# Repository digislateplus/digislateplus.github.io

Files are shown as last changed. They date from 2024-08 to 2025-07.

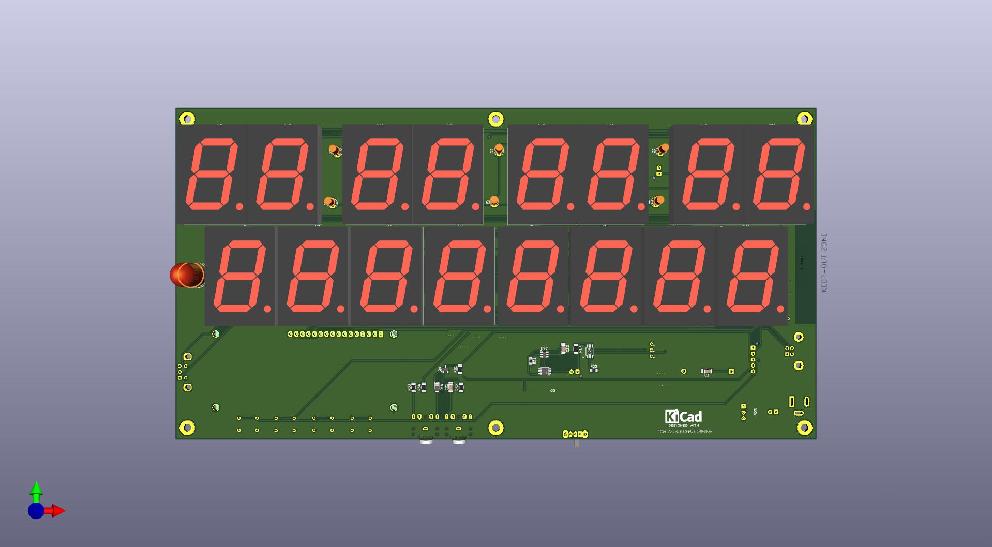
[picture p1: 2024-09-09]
hardware/PCB/gallery/DigiSlatePlus front.jpg

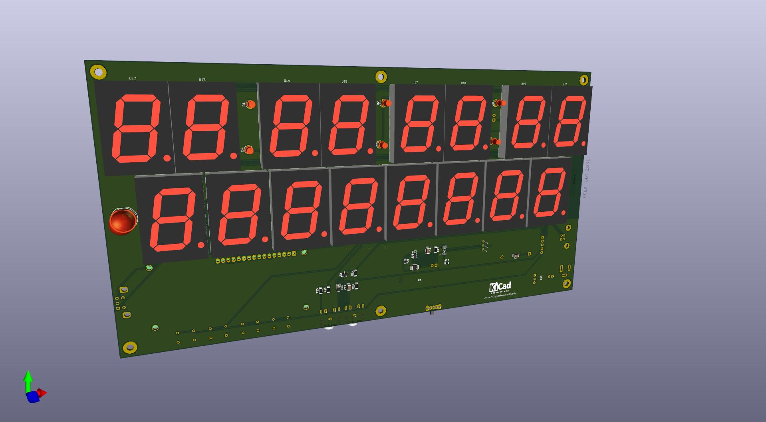
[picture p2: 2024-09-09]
hardware/PCB/gallery/DigiSlatePlus.jpg

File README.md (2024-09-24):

# DigiSlate+

DigiSlate+ is based on the [DigiSlate](https://www.youtube.com/watch?v=TnaWQZtmPek) and is inspired by the DIY timecode generator from [mitkunz](https://github.com/mitkunz/diy_timecode_generator). The aim for the DigiSlate+ is not only to be able to read and display timecode, but also to generate it itself. To make this possible, the hardware is extended by a real time clock with high running accuracy. The RTC module DS3231 with temperature-compensated quartz offers the possibility.

There are two versions of the DigiSlate+. The simpler version is based on modified hardware from the original DigiSlate project and the software in the master branch.

The newly developed hardware offers significantly more functions. The corresponding code can be found in the dotmatrix branch.

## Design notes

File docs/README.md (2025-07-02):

# DigiSlate+

- [Hardware](hardware.md)
- [Functions](function.md)
- [ToDos](todos.md)
- [Code](https://github.com/digislateplus/digislateplus.github.io)

DigiSlate+ is based on the [DigiSlate](https://www.youtube.com/watch?v=TnaWQZtmPek) and is inspired by the DIY timecode generator from [mitkunz](https://github.com/mitkunz/diy_timecode_generator). The aim for the DigiSlate+ is not only to be able to read and display timecode, but also to generate it itself. To make this possible, the hardware is extended by a real time clock with high running accuracy. The RTC module DS3231 with temperature-compensated quartz offers a maximum drift of two minutes per year or 8 frames in a day.

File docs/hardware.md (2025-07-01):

# Hardware

[Home](README.md)

The hardware is based on an ESP32S3 microcontroller, which supplies the time code, controls the displays and can connect to other devices via WiFi and Bluetooth.

All components are combined on a central circuit board, only the switch for recognising the flap, the main switch and the battery are connected via JST-XH connectors.

The 7-segment LED displays for the time code, scenes and take numbers are located on the front. The rear has the LC display, four buttons and a rotary encoder for controlling the functions.

The real-time clock has its own battery, which enables a long running time when the DigiSlate+ is switched off.

A 3.5mm jack is used for the input and output of the timecode. The DigiSlate+ can be powered via a 5.5x2.5mm DC plug. The DigiSlate can be supplied with a voltage between 8 volts and 24 volts via a 5.5 x 2.5 mm DC plug and the internal battery can be charged.

* [download]({{ site.baseurl }}{% link DigitSlate+ Schematics.pdf %})
* [download]({{ site.baseurl }}{% link DigitSlatePlus__Assembly.pdf %})

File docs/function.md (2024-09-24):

# Operation
## Start
The DigiSlate+ is put into operation using the switch on the bottom. After a short initialization, the time is read from the real-time clock. The time code is synchronized with the exact time base of the real-time clock and "init" is shown on the LC display.

Once initialization is complete, the time code starts running on the LED display. The LC display on the back shows "run" as well as the set frame rate and the user bits.

If the DigiSlate+ is operated, the sync LEDs flash and the time code display remains for three seconds. "clap" is shown on the LC display. After that, the time code continues to run again.

## Time code output
The time code is output at the tip of the 3.5 mm jack socket as an LTC with a voltage of 1 volt peak-to-peak.

## Time code input
An external time code can be fed in via the ring of the 3.5 mm jack socket.  The DigiSlate+ recognizes this and switches to reading mode. The read time code is shown on the LED display and the LC display shows "sync".

The time in the real-time clock is not changed. When the time code entry is finished, the DigiSlate+ goes back to "run" mode and shows the time of the real-time clock.

### Jam
The external time code can be transferred to the real-time clock.

1. Switch off the DigiSlate+

2. Feed the external time code via the 3.5mm jack socket
3. Switch on the DigiSlate+

It is in "jam" mode, which is shown on the LC display. The time code is transferred to the real-time clock as soon as it is folded once.

## Setup
Parameters of the DigiSlate+ can be set in the setup.

- Set time code
- Set user bits
- Select frame rate

### Start
The setup mode is started as follows.

1. Turn off the DigiSlate+
2. Turn on the DigiSlate+
3. When the text "tripple clap to enter setup" appears, quickly clap the DigiSlate+ three times.

"SETUP" will now appear on the LCD display.

(more to come)

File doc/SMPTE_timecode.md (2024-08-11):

# SMPTE/EBU timecode structure
[WikiAudio](https://www.wikiaudio.org/smpte-time-code/)

| Byte | Bit | content|
|---|-----|---|
| 0 | 0-3 |	frame units |
| 0 | 4-7 | user bits 1 |
| 1 | 8-9 | frame tens |
| 1 | 10  | dropframe bit*(1)* |
| 1 | 11  |	colorframe bit*(2)* |
| 1 | 12-15 | user bits 2 |
| 2 | 16-19 | seconds units |
| 2 | 20-23 | user bits 3 |
| 3 | 24-26 | seconds tens |
| 3 | 27 | bi phase mark correction bit |
| 3 | 28-31 | user bits 4 |
| 4 | 32-35 | minutes units |
| 4 | 36-39 | user bits 5 |
| 5 | 40-42 | minutes tens |
| 5 | 43 | binary group flag bit*(3)* |
| 5 | 44-47 | user bits 6 |
| 6 | 48-51 | hours units |
| 6 | 52-55 | user bits 7 |
| 7 | 56-57 | hour tens |
| 7 | 58 | unused, reserved(*4*) |
| 7 | 59 | binary group flag bit*(5)* |
| 7 | 60-63 | user bits 8 |
| 8-9 | 64-79 | sync word*(6)* |

(1) 1=drop frame (frame 0 and 1 omitted from first second of each minute, but included when minutes divides by ten; approximates 29.97 frame/s)

(2) i.e. the time code is intentionally synchronised with a color TV field sequence.

(3) (with bit 59, 43,59 = 00 = no format for user bits, 10 = eight bit format, 01, 11 are unassigned and reserved).

(4) should transmit zero and ignore on receive for compatibility

(5) see bit 43 for encoding

(6) 0011 1111 1111 1101

# Signal
After every bit the output is inverted. A logical 1 changes the polarity in the middle of the bit clock. The data is sent starting with the least significant bit of each byte.

The interrupt frequence depends on the framerate and is controlled by the compare register of timer 1 from the Atmega328.

- 24 fps => 3840 Hz; cmr = 4166
- 25 fps => 4000 Hz; cmr = 4000
- 30 fps => 4800 Hz; cmr = 3332

The initial settings of the cmr value are synchroniced by measuring two times. The actual time that passed between two interrupts from the realtime clock is compared with a  sequence to send timecode, controlled by the timer 1 interrupt. The compare register is increated, if the timecode output is too fast, and decreases the value, if the timecode is too slow. So the accuracy of the timecode output is privided.

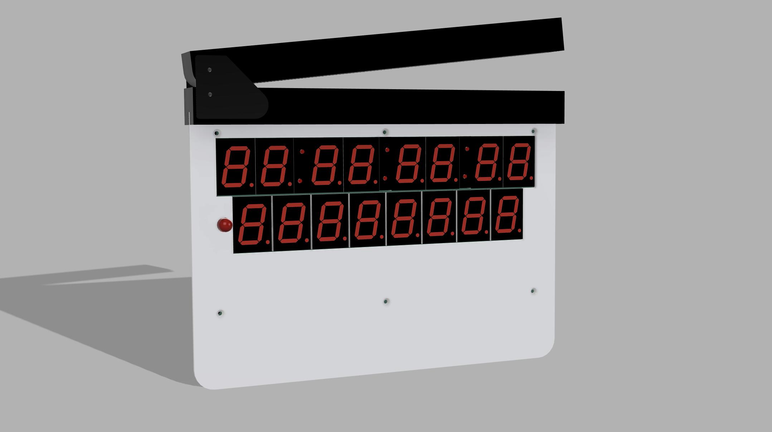
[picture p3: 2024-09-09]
hardware/PCB/gallery/DigiSlate+ v3.jpg

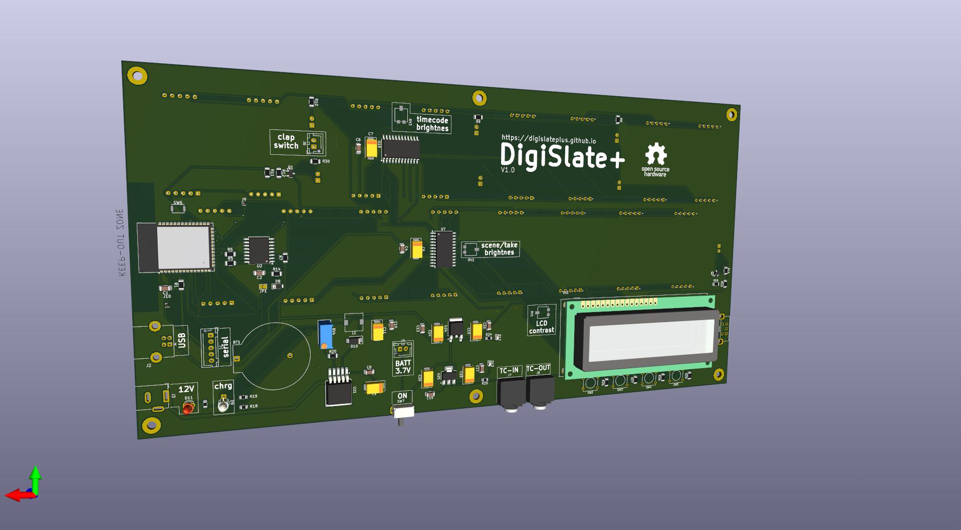
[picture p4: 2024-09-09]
hardware/PCB/gallery/DigiSlatePlus back.jpg

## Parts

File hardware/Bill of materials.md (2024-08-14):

# MAX Electronics  
### SMPTE DigiSlate Model:2SWF9  
Rev: 1.0  
Bill Of Material

https://m.youtube.com/watch?v=TnaWQZtmPek&pp=ygUYbWF4ZWxlY3Ryb25pY3MgZGlnaXNsYXRl

## Resistors:  
|Nr|value|package|Lieferant|  
|--|-----|---|---|
|R1,4,5,6|10K|0805|**ok**|
|R2,3|10K|1206|**ok**|
|R9-12|100R|1206|**ok**|
|R13-15|470R|1206|**ok**|
|R16|360R|1206|**ok**|
|R17-19|1K|0805|**ok**|
|R20|15K|1206|**ok**|
|R21|1.5K|1206|**ok**|
|R22|2.2K|1206|**ok**|
|R23|2.7K|1206|**ok**|
|RV1|20K|TS53YJ|**ok**|
|RV3|10K|TS53YJ|**ok**|
|RV2|10K|3296W|**ok**|

## Ceramic Caps:  
|Nr|value|package|Lieferant|  
|--|-----|---|---|
|C1,3,4|100nF/50v|0805|**ok**|
|C5|100nF/50v|1206|**ok**|
|C2|100nF/50v|5mm|**ok**|
|C9,10,12|10nF/50v|1206|**ok**|
|C13|22uF/50v|1210|**ok**|
|C14|1uF/50v|0805|**ok**|

## Electrol. Caps:  
|Nr|value|package|Lieferant|  
|--|-----|---|---|
|C15,16|220uF/25v|8x10|**ok**|

## Tantalum Caps:  
|Nr|value|package|Lieferant|  
|--|-----|---|---|
|C17|470uF/10v|Kemet-D|**ok**|
|C18,19|100uF/10v|Kemet-D|**ok**|
|C20,21|100uF/10v|Kemet-T|**ok**|

## LED/Diodes: 
|Nr|value|package|Lieferant|  
|--|-----|---|---|
|D1,2|SS310|SMA|**ok**|
|D3|1N4148|1206|**ok**|
|LD1,2|Red Clear|10mm|**ok**|
|LD3-8|Red Dif Flat|3mm|**ok**|
|LD9|R/G, Com-A|3mm|**ok**|

## Displays:  
|Nr|value|package|Lieferant|  
|--|-----|---|---|
|HR1,2|12101AS|7Segment|**ok**|
|MN1,2|12101AS|7Segment|**ok**|
|SC1,2|12101AS|7Segment|**ok**|
|FR1,2|12101AS|7Segment|**ok**|
|DS1|WC1602A|Dot-Mtrx|**ok**|

## IC’s:  
|Nr|value|package|Lieferant|  
|--|-----|---|---|
|U1|Atmega 328p-AU|TQFP-32|**ok**|
|U2|MAX7219|SOIC-24W|**ok**|
|U3|MT3608|SOT-23-6|EBay|
|U4|78M05|TO-252-2|**ok**|
|U5|LM2596S|TO-263-5|**ok**|
|U6|TP4056|SOP8|lagernd|
|U8|PC817|DIP4|**ok**|
|Q1-4|MMBT2222 (BC337)|SOT-23|**ok**|

## Inductor:  
|Nr|value|package|Lieferant|  
|--|-----|---|---|
|L1|22uH|7.3x7.3mm|**ok**|
|L2|68uH|7.3x7.3mm|**ok**|

## Miscellaneous:  
|Nr|value|package|Lieferant|  
|--|-----|---|---|
|CN1,2|2Pin Molex|P:2.54mm|**ok**|
|CN3|BNC|Panel MT|fehlt|
|CN4|2x3 Header|P:2.54mm|**ok**|
|CN5|Barrel Jack|5.5x2.1mm|**ok**|
|CN6|3.5 TRS Jack|SJ1-3525N|**ok**|
|SW1|1x2-Header-P:2.54mm||**ok**|
|SW2|NO Reed Switch|P:25mm|fehlt|
|Y1|Crystal-16Mhz|CSTxExxV|**ok**|

# Software
https://github.com/mitkunz/diy_timecode_generator

# Hardware-Anpassungen
Zusätzliches RTC-Modul DC3231
- Atmega Pin 1 (PD3/D3) => Pin 26 (PC3/D17) - WC1602C Pin 14 (D7) (ändern der LCD-Library)
- Atmega Pin 1 (INT1) => DC3231 SQW
- Atmega Pin 27 (SDA) => DC3231 SDA
- Atmega Pin 27 (SCL) => DC3231 SCL
# Interrupt 
**timer 1 settings**
i=interrupt frequency (Hz) = (Arduino clock speed c=16,000,000Hz) / (p=prescaler * (c=compare match register + 1))

compare match register = [ 16,000,000Hz/ (prescaler * desired interrupt frequency) ] - 1

timer1, prescaler 1

24fps => 3840Hz => 260us; cmr=4166
25fps => 4000Hz => 250us; cmr=4000
30fps => 4800Hz => 208us; cmr=3332

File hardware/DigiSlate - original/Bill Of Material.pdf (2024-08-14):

# MAX

# Electronics

## SMPTE DigiSlate Model:2SWF9

# Rev: 1.0 Bill Of Material

# Resistors:

R1,4,5,6----------- 10K------------0805 R2,3-----------------10K -----------1206 R9-12---------------100R----------1206 R13-15--------------470R----------1206 R16------------------360R----------1206 R17-19---------------1K------------0805 R20------------------15K------------1206 R21------------------1.5K-----------1206 R22------------------2.2K-----------1206 R23------------------2.7K-----------1206

RV1------------------20K--------TS53YJ RV3------------------10K--------TS53YJ RV2 -----------------10K---------3296W

# Ceramic Caps:

C1,3,4-----------100nF/50v-------0805 C5----------------100nF/50v-------1206 C2----------------100nF/50v-------5mm C9,10,12---------10nF/50v-------1206 C13----------------22uF/50v-------1210 C14----------------1uF/50v---------0805

# Electrol. Caps:

C15,16----------220uF/25v------- 8x10

# Tantalum Caps:

C17------------470uF/10v----Kemet-D C18,19--------100uF/10v----Kemet-D C20,21--------100uF/10v----Kemet-T

# LED/Diodes:

D1,2--------------SS310------------SMA D3---------------1N4148------------1206 LD1,2---------Red Clear---------10mm LD3-8--------Red Dif Flat---------3mm LD9-----------R/G, Com-A--------3mm

# Displays:

HR1,2---------12101AS----7Segment MN1,2---------12101AS----7Segment SC1,2---------12101AS---- 7Segment FR1,2---------12101AS---- 7Segment DS1-----------WC1602A------Dot-Mtrx

# IC’s:

U1------Atmega 328p-AU---TQFP-32 U2-------------MAX7219---SOIC-24W U3--------------MT3608------SOT-23-6 U4----------------78M05------TO-252-2 U5--------------LM2596S----TO-263-5 U6---------------TP4056----------SOP8 U8----------------PC817------------DIP4 Q1-4---------MMBT2222------SOT-23

# Inductor:

L1-----------------22uH-----7.3x7.3mm L2-----------------68uH-----7.3x7.3mm

# Miscellaneous:

CN1,2--------2Pin Molex---P:2.54mm CN3---------------BNC--------Panel MT CN4-----------2x3 Header--P:2.54mm CN5----------Barrel Jack--5.5x2.1mm CN6------3.5 TRS Jack---SJ1-3525N SW1-----------1x2-Header-P:2.54mm SW2-----NO Reed Switch--- P:25mm Y1-------Crystal-16Mhz---CSTxExxV

# END

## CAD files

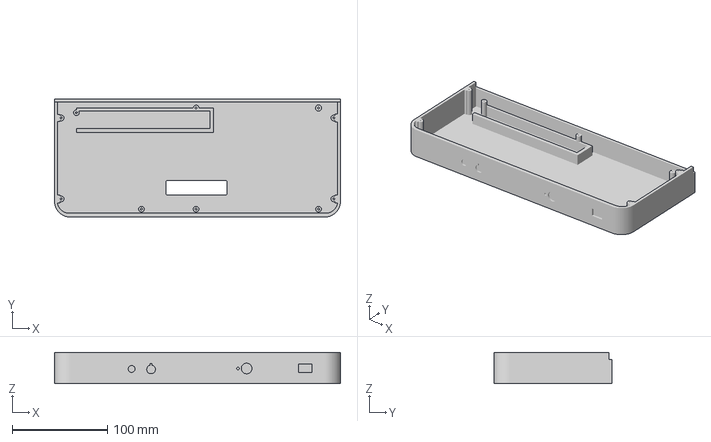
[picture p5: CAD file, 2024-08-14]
hardware/DigiSlate - original/3D Print/Digislate Full.3mf
300.0 x 124.0 x 33.0 mm

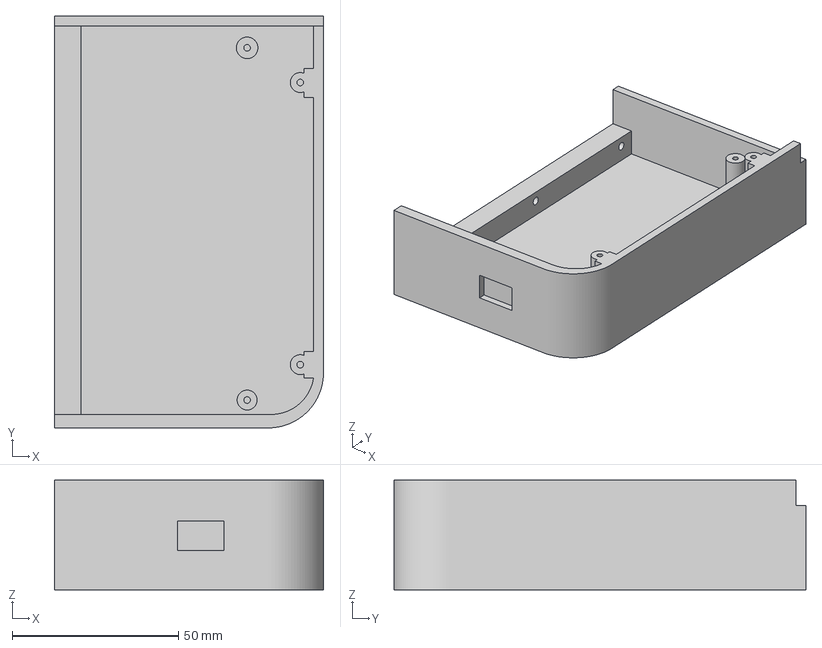
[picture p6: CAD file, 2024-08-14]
hardware/DigiSlate - original/3D Print/Small Part 1 Digislate.3mf
81.0 x 124.0 x 33.0 mm

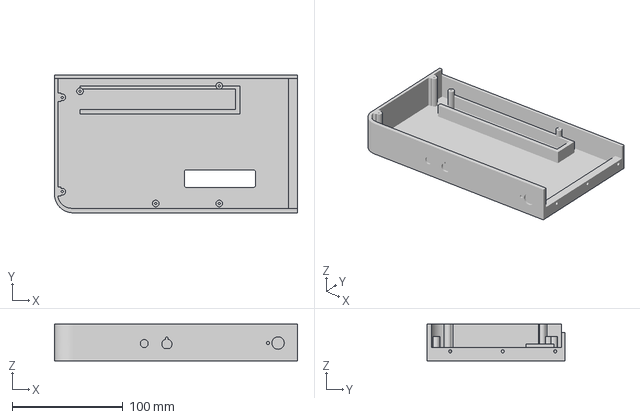
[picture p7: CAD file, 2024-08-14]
hardware/DigiSlate - original/3D Print/Large Part 2 Digislate.3mf
219.0 x 124.0 x 33.0 mm

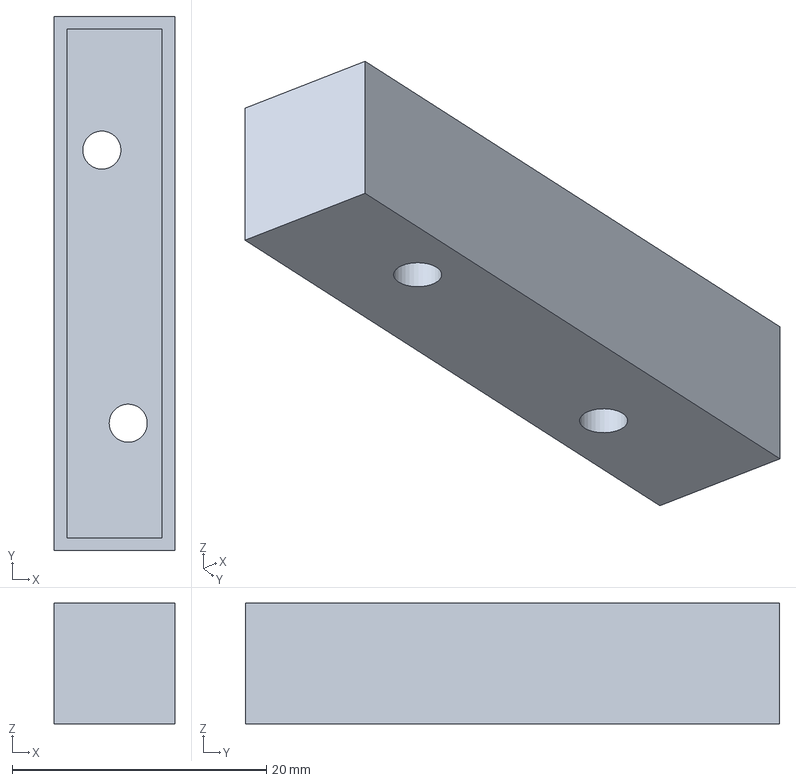
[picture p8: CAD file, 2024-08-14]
hardware/DigiSlate - original/3D Print/Divider for 7 Segments.3mf
9.50 x 42.0 x 9.50 mm

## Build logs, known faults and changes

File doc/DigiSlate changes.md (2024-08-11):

# Changes to the original DigiSlate design

This project is based on the [DigiSlate by Max Christensen](https://www.youtube.com/watch?v=TnaWQZtmPek). Some adaptations have been made to add the timecode generator function, which are listed here.

## RTC-Module
A DS3231 real-time clock module has been added to the bottom right of the PCB (seen from the front). Five isolated areas in the GND area on both sides of the board have been scratched free. The RTC module can be soldered in through six holes, whereby the GND connection is located directly in the GND area. The VCC is provided from C20 with a short wire. The 32k output of the RTC keeps unused.

## Atmega328
In order to connect the RTC module, some changes must be made around the Atmega328 microcontroller.

### Interrupt
Pin 1 (PD3/INT1) is required for the interrupt of the RTC interrupt from the squarewave output (SQW). The pin is used as D7 line for the LC display and must be changed. The trace can be cut directly next to the Atmega pin before the through-connection. A wire connects the SQW output of the RTC to pin 1.

Pin 17 (D17/PC3) is unused and can be connected directly to pin 14 of the LCD module with a short wire. In the LCD class, D7 has be routed to output 17 (see setup.h).

### I2C
The SDA and SCL connectors of the rtc module are connected to Pin 27 (SDA) and Pin 28 (SCL) of the Atemga328 using thin wires.

## 3,5mm Jack
The trigger out is scipped and used as output of the timecode signal with a audio line level.

The U8 opto coupling chip is removed. A 5k6 resistor is soldered between pins 1 and 2 of  jumper 1 and pin 3 of the former opto coupler on the backside of the PCB. On the front side a 1k8 resistor connects pin 3 of the former opto coupler with the GND pin of the Jach connector. This creates a voltage devider the provides a signal of aroun 1 Volt on the output.

The pin 30 (D0/PD0) of the Atmega is used as output for the timecode (see setup.h).

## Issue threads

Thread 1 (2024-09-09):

RTC loading

digislateplus, 2024-09-09:
Add the resistor and diode to load a rechargable lithium battery for the rtc module. Add a jumper to set, if a recharchable type is used (closed) or a normal battery is inserted (open).

Closed 2024-09-09.

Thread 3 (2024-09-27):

Design issues on new hardware

digislateplus, 2024-09-27:
In the pbc layout of version 1.0 there are the following errors:

R23: silkscreen on wrong side (corrected in KiCAD V1.1)
U23: TP4056 ESOB8 instead of SOP8 footprint (corrected in KiCAD V1.1)
MT3608 step up converter missing (added in KiCAD V1.1)

digislateplus, 2024-10-08:
level converter for connecting ESP32 and MAX7219 needed

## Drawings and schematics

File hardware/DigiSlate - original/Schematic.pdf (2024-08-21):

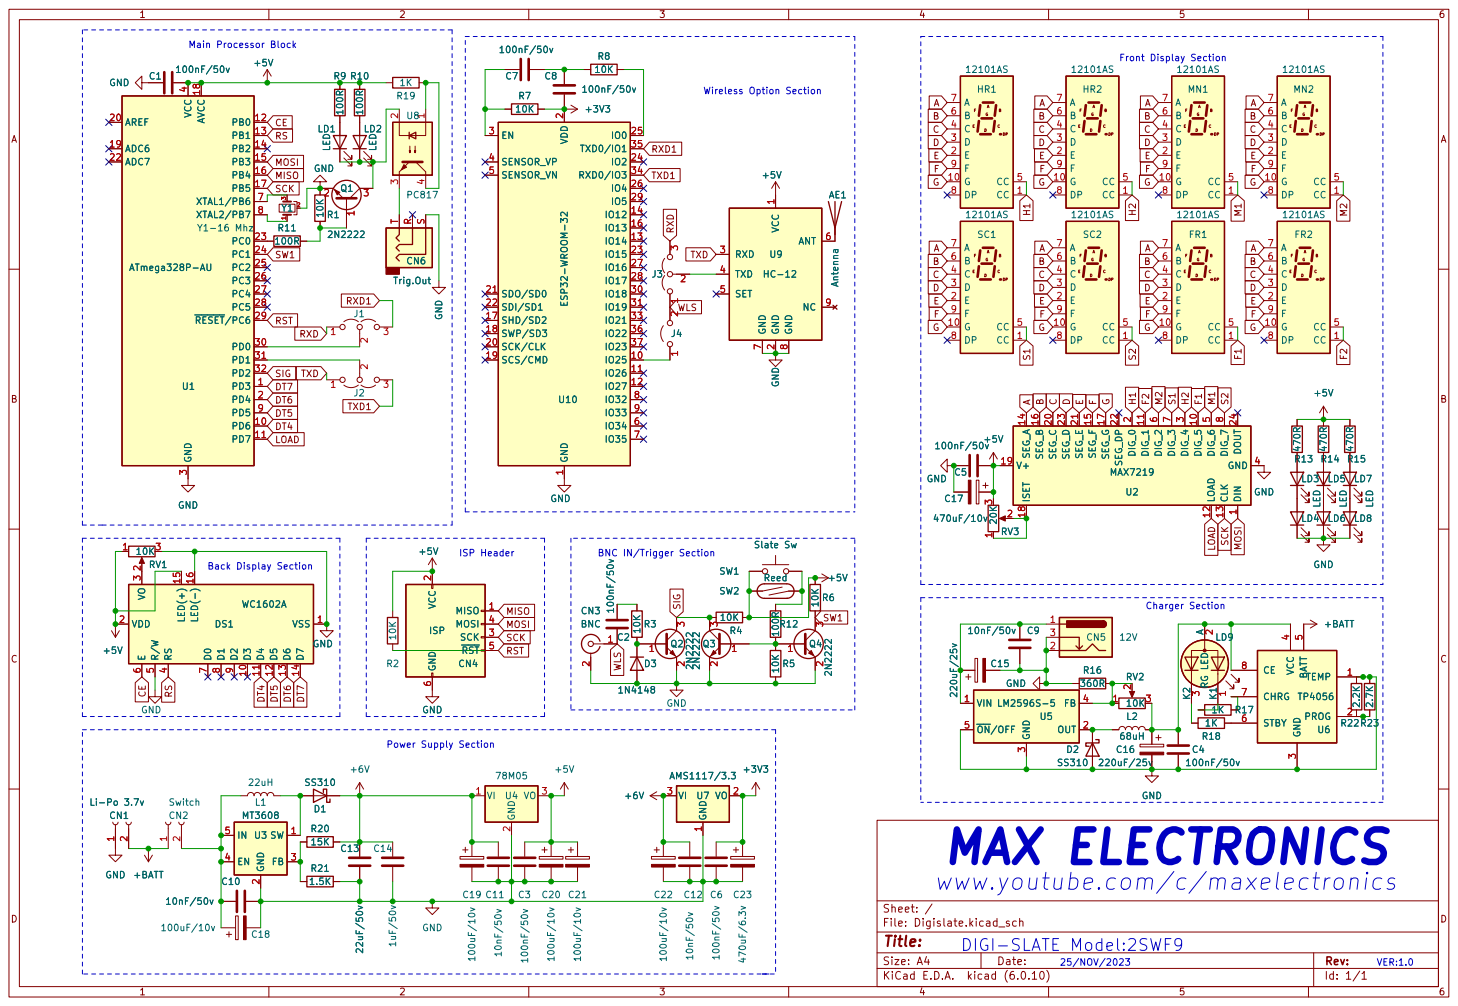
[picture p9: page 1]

2 SCK/CLK 20 SDO/SD0 21 SDI/SD1 22

2 RXD 3 TXD 4 SET 5 ANT 6 GND
TXD

BNC IN/Trigger Section

2 SCK 3 MOSI 4 ~{RST} 5 GND

1 VO 2 VI 3 U7 AMS1117/3.3 VI 1 GND

MAX ELECTRONICS
www.youtube.com/c/maxelectronics

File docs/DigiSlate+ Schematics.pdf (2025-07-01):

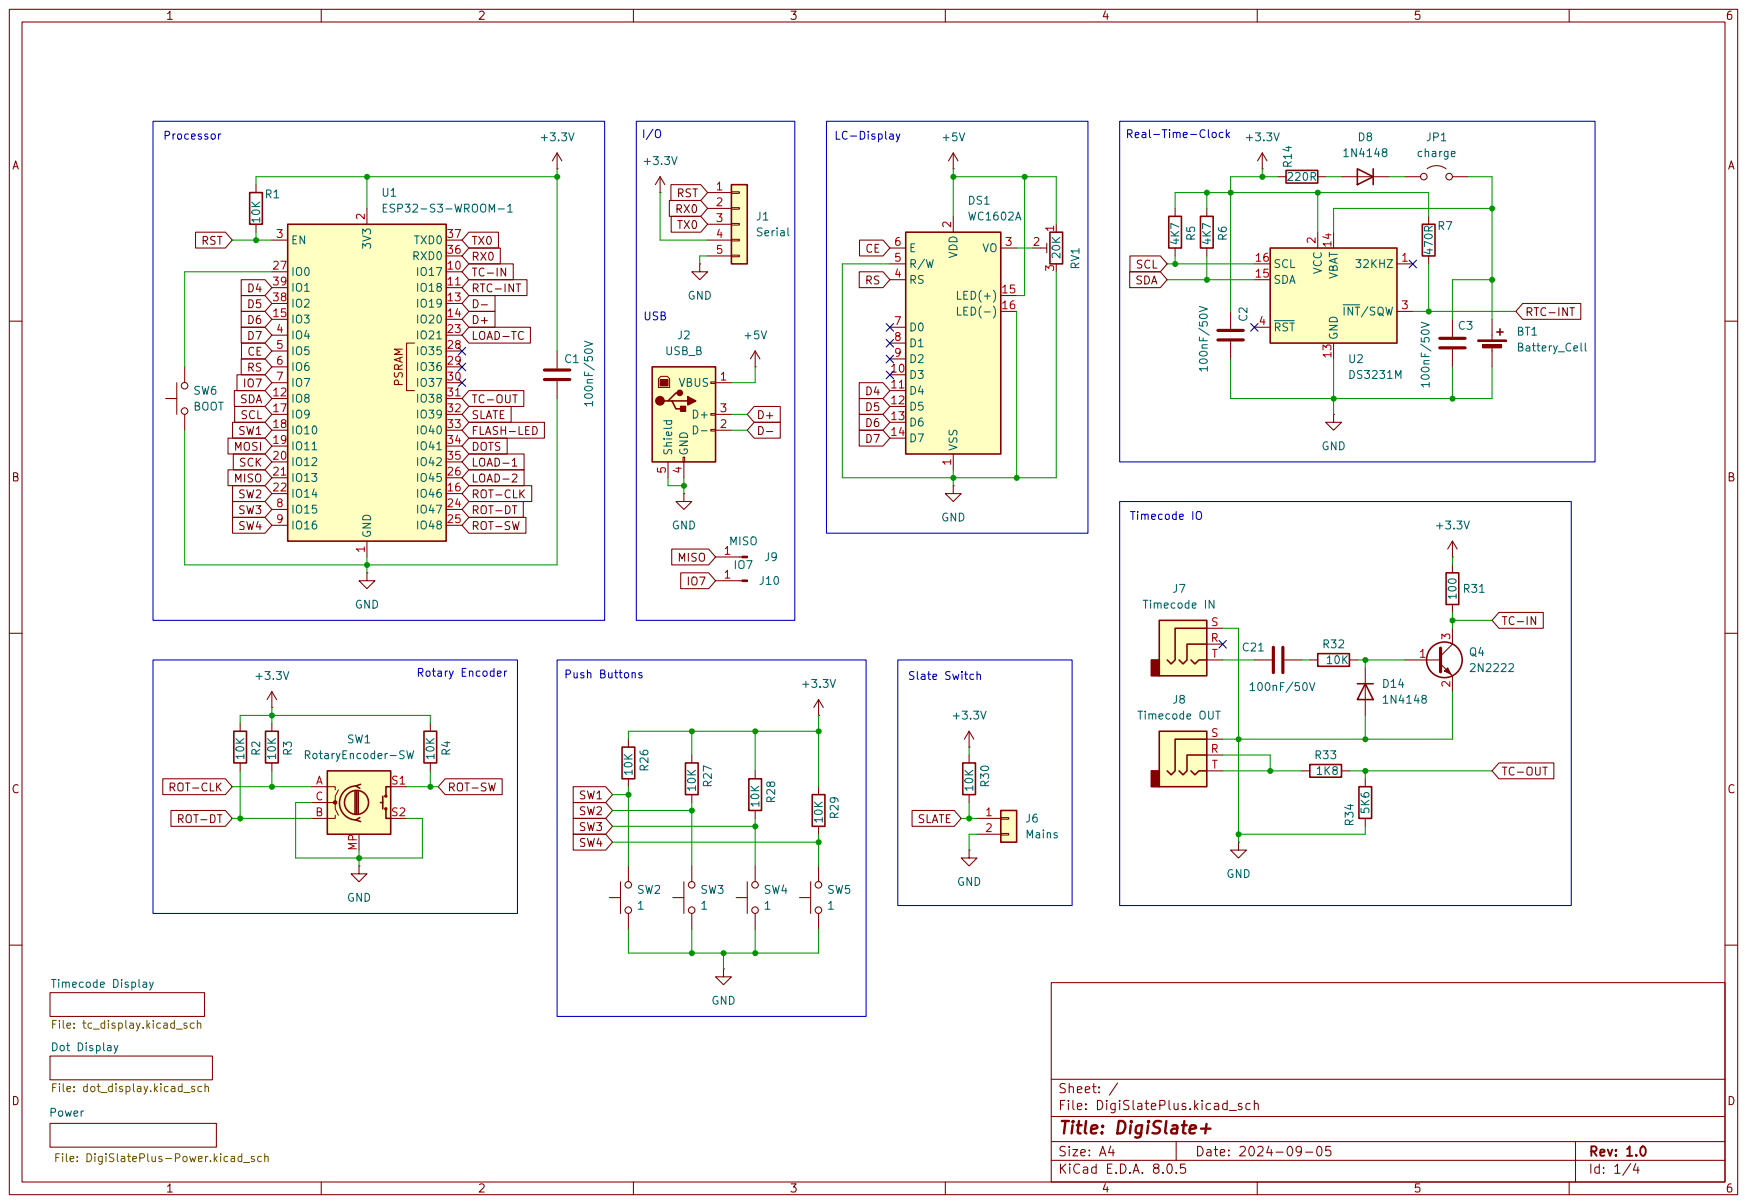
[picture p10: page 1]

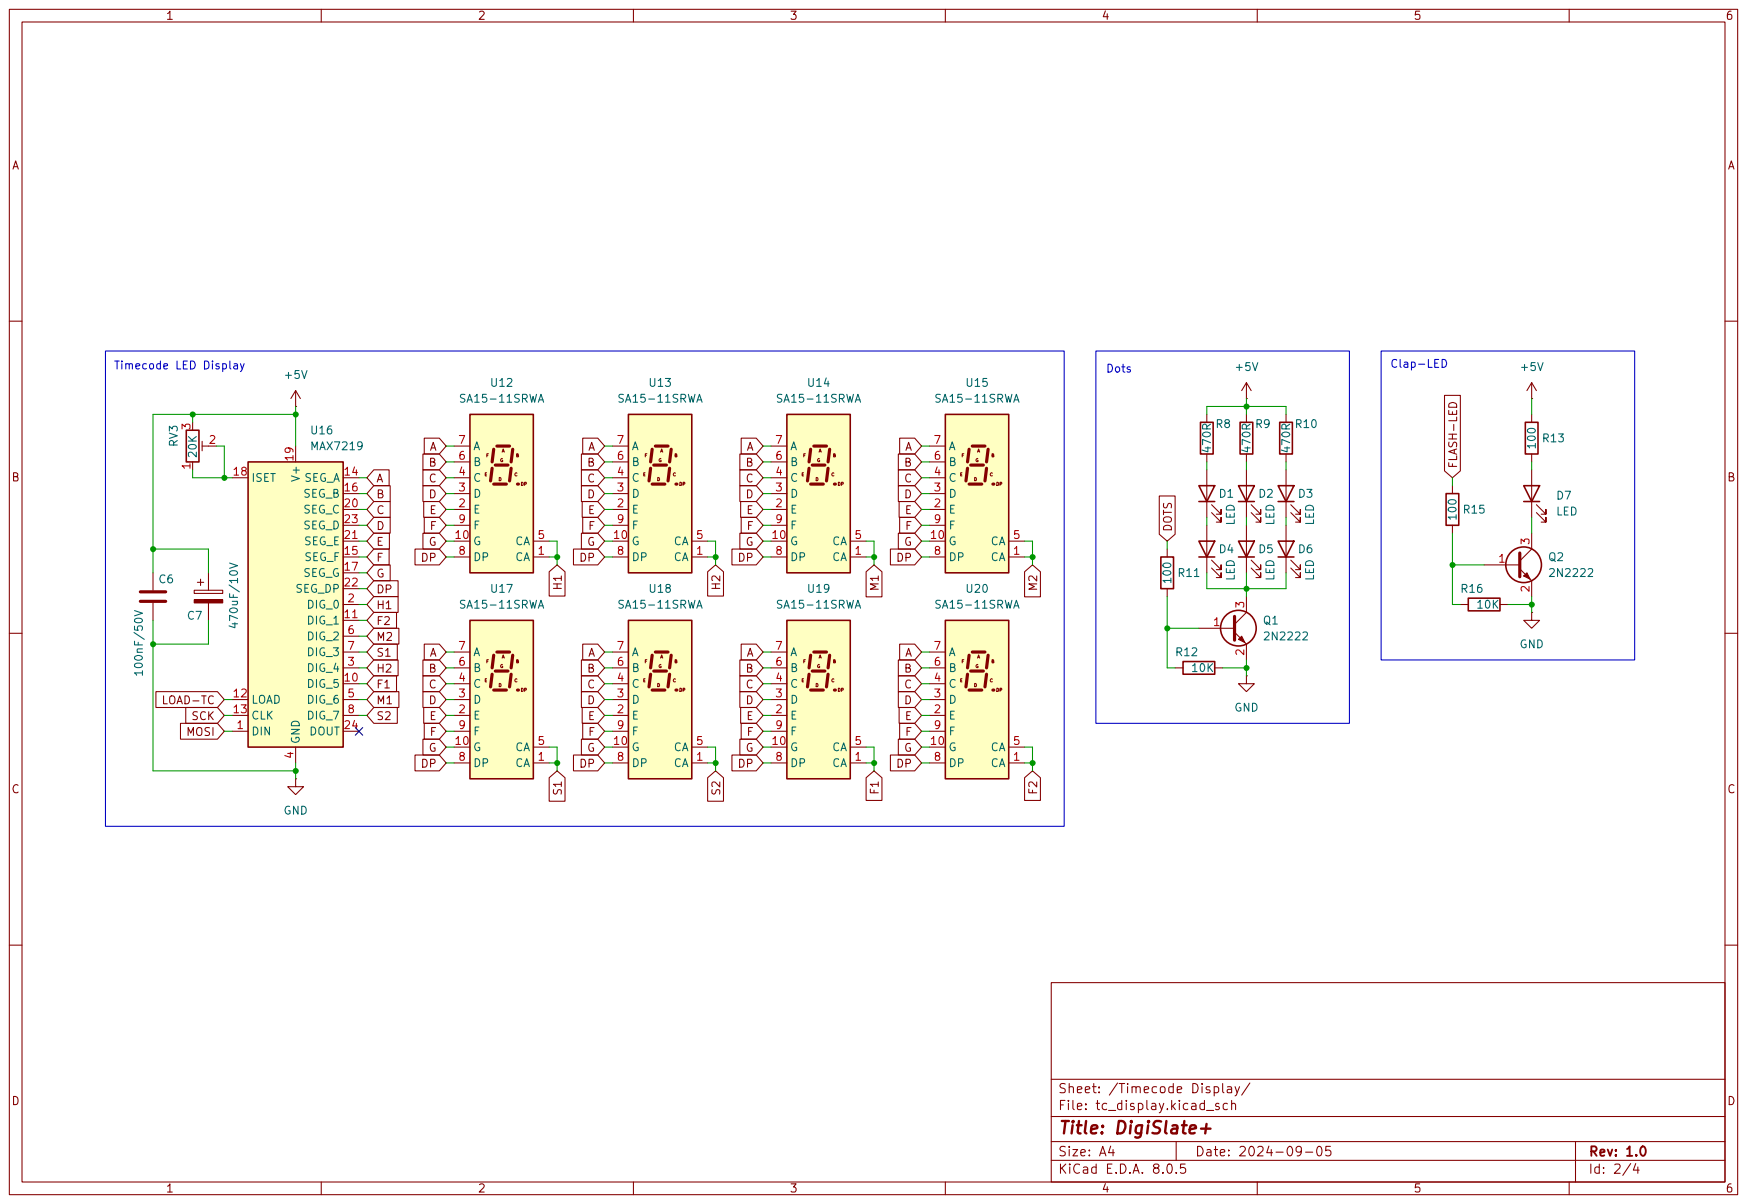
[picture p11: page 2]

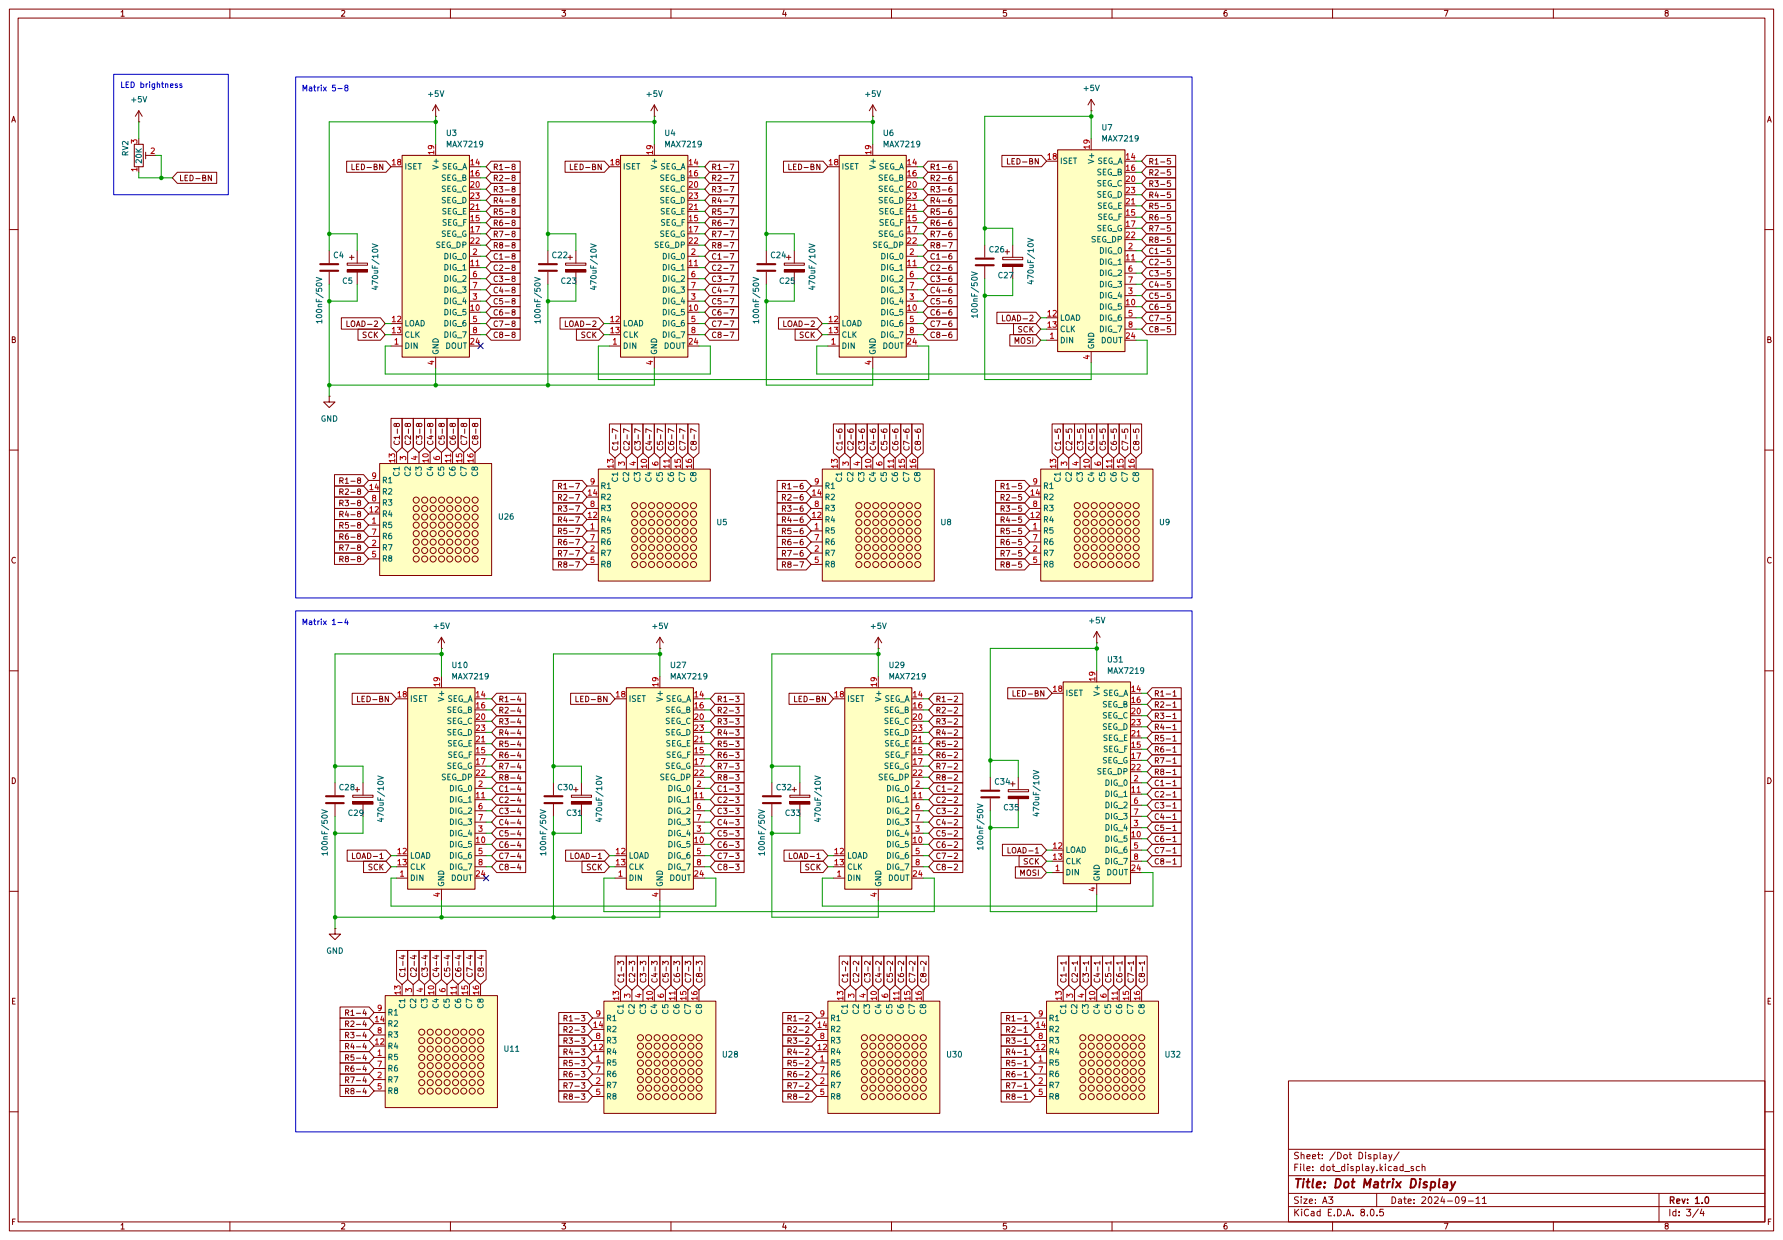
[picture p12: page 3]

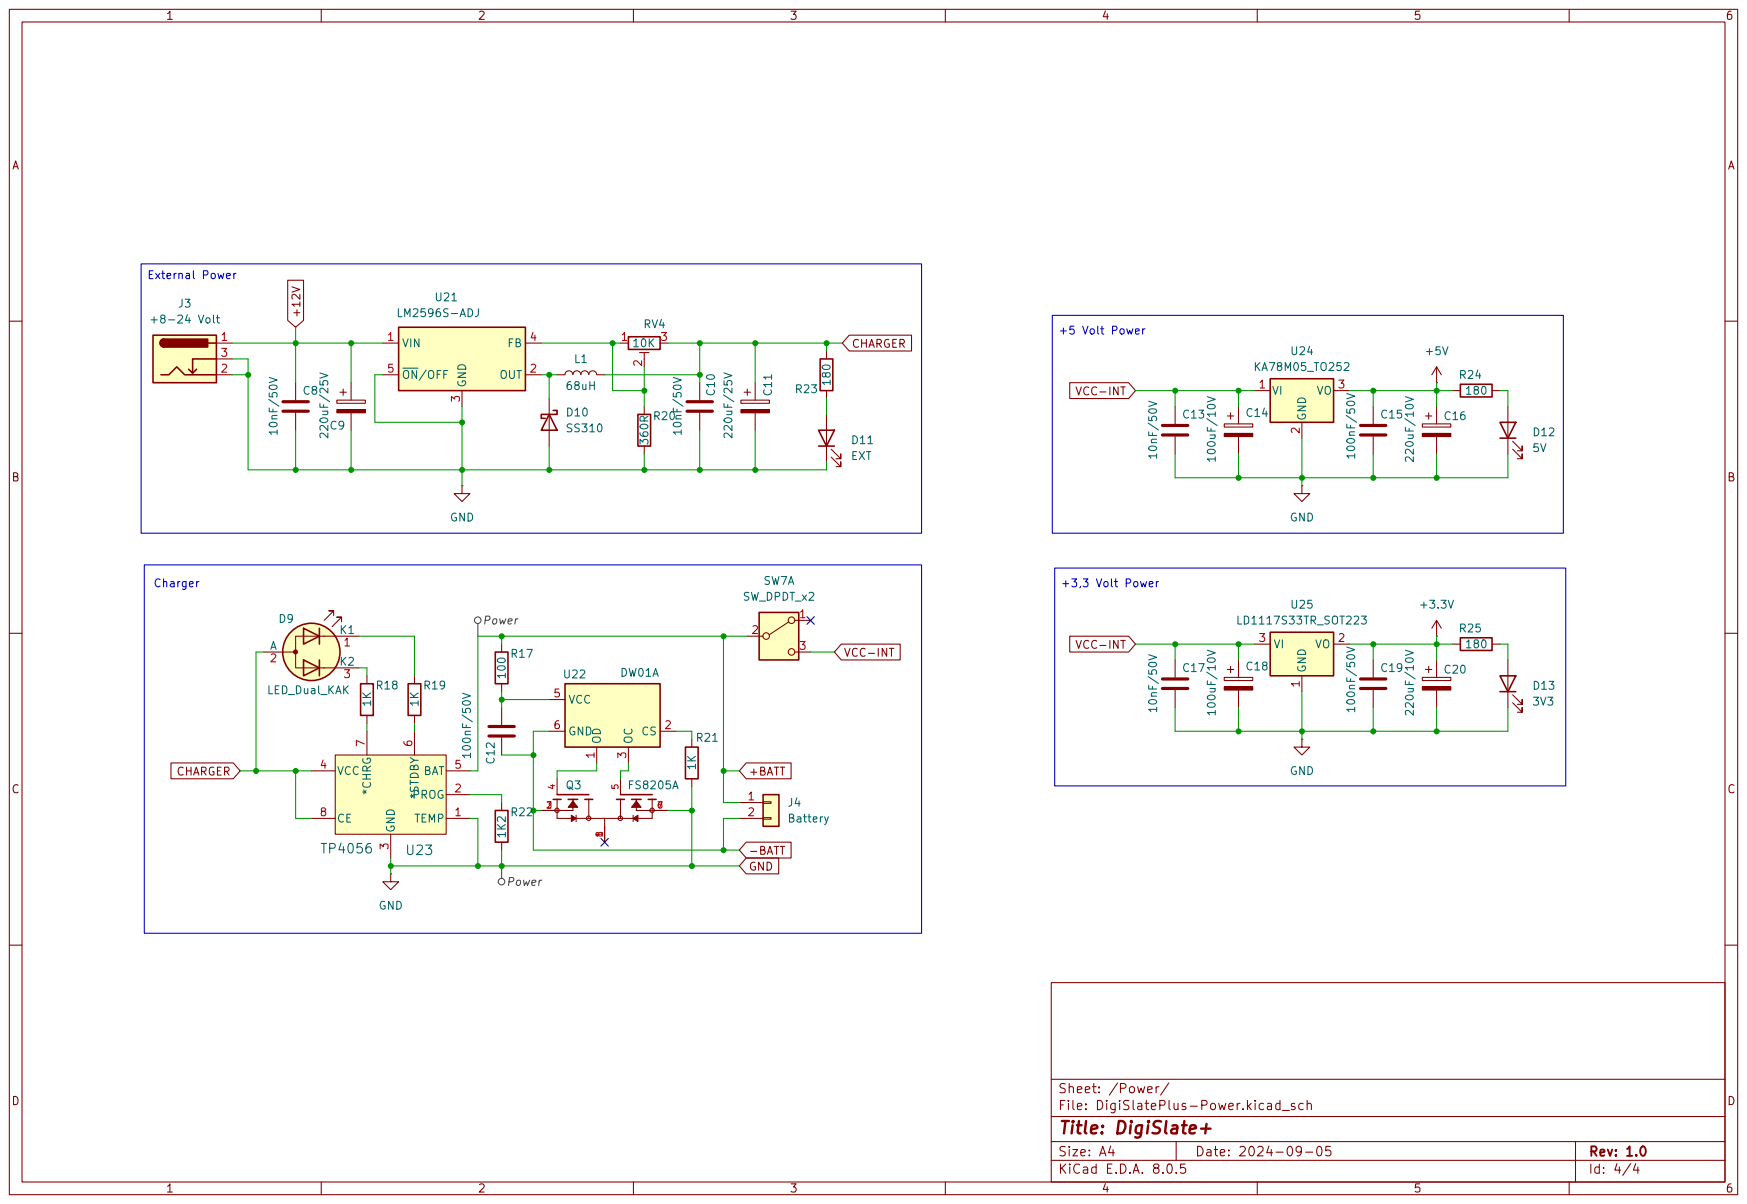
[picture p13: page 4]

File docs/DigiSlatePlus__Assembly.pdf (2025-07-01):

U32 U14 | U17 | C³⁶
U13 | R³⁴

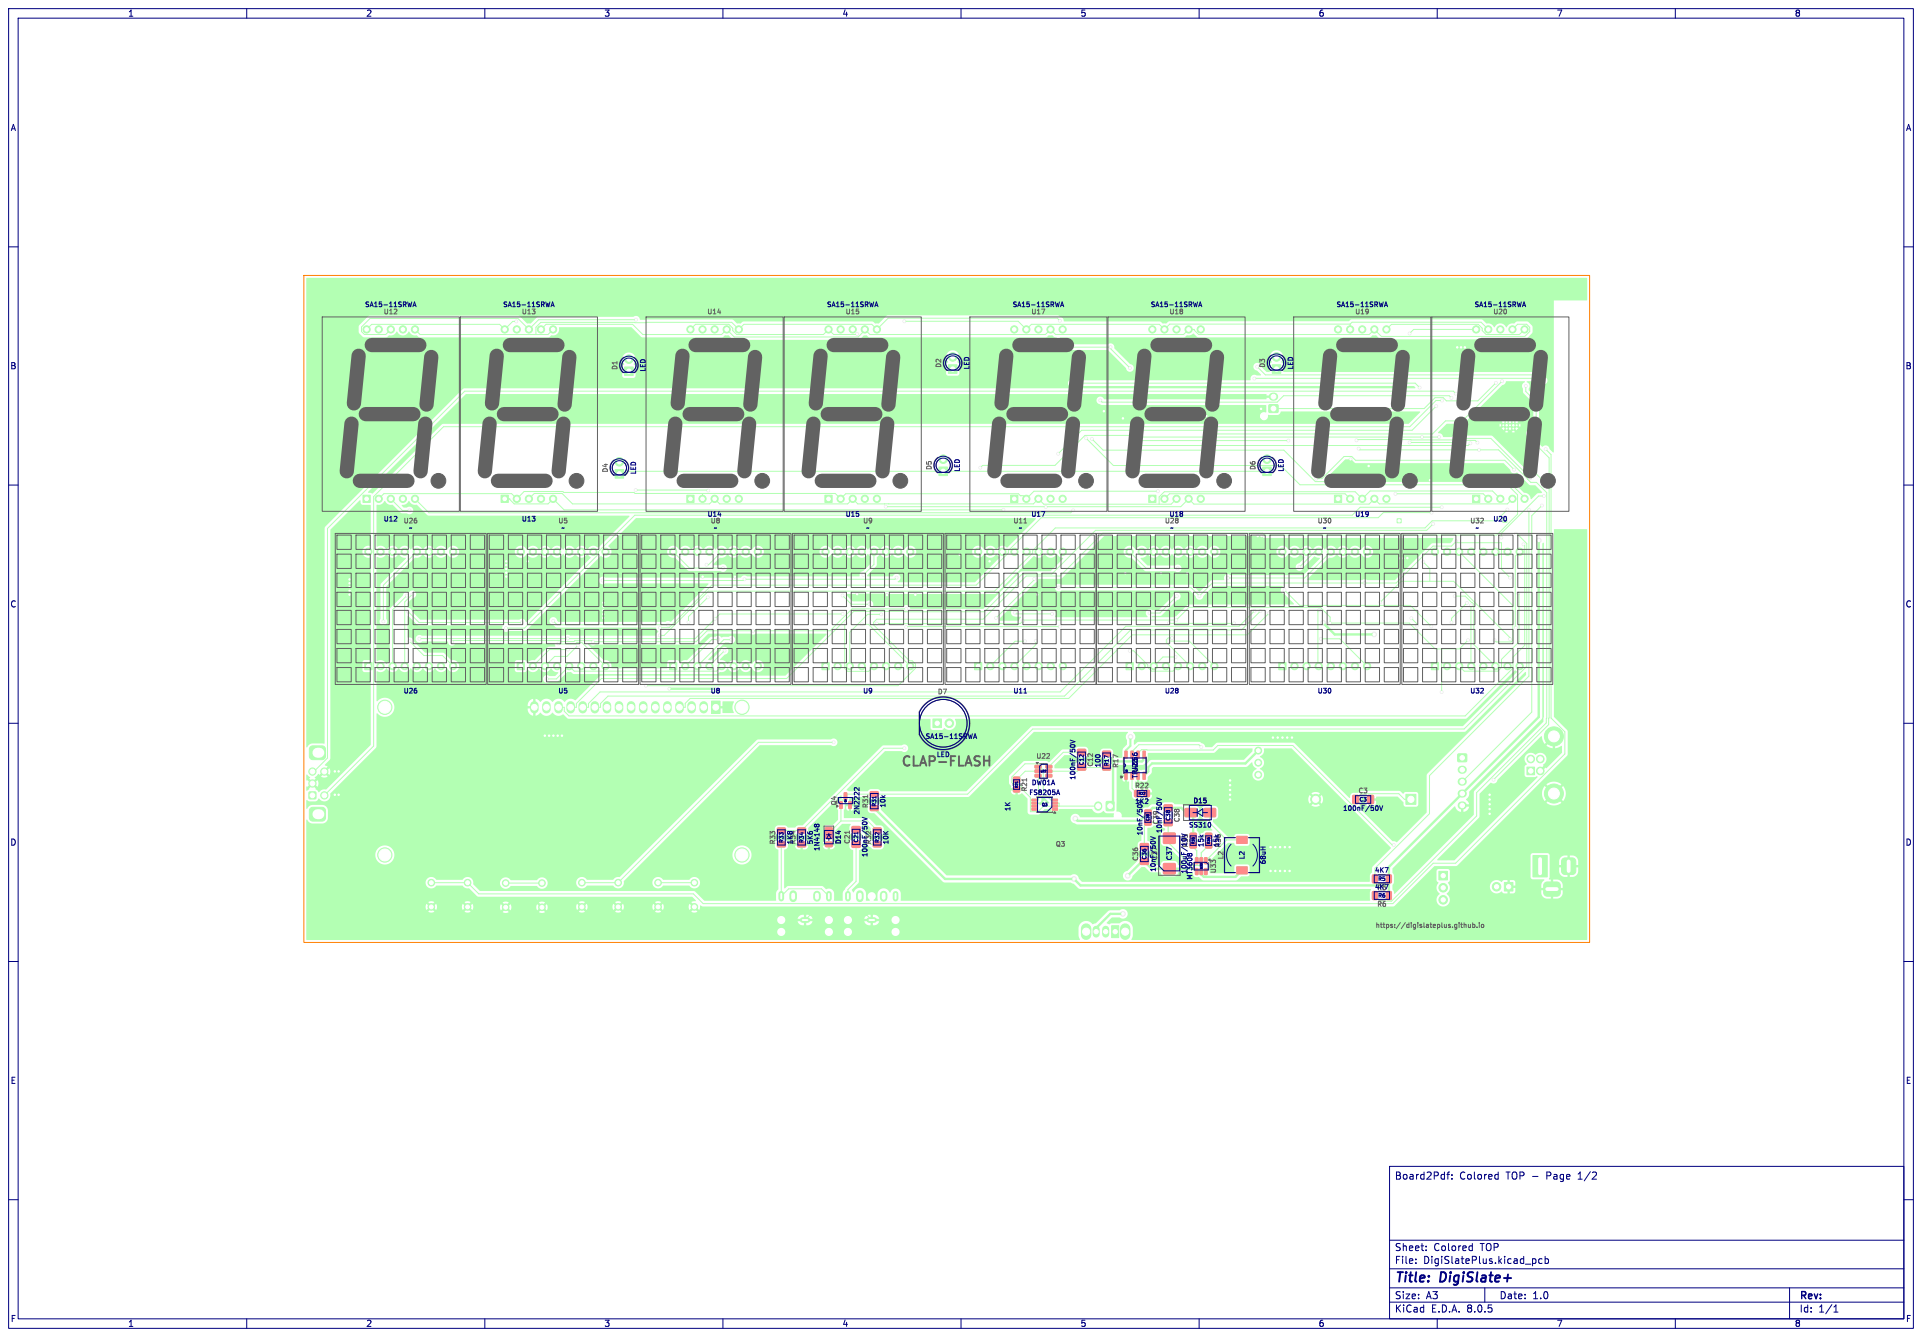
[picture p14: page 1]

1 | 2 | 3 | 4 | 5 | 6 | 7 | 8

A

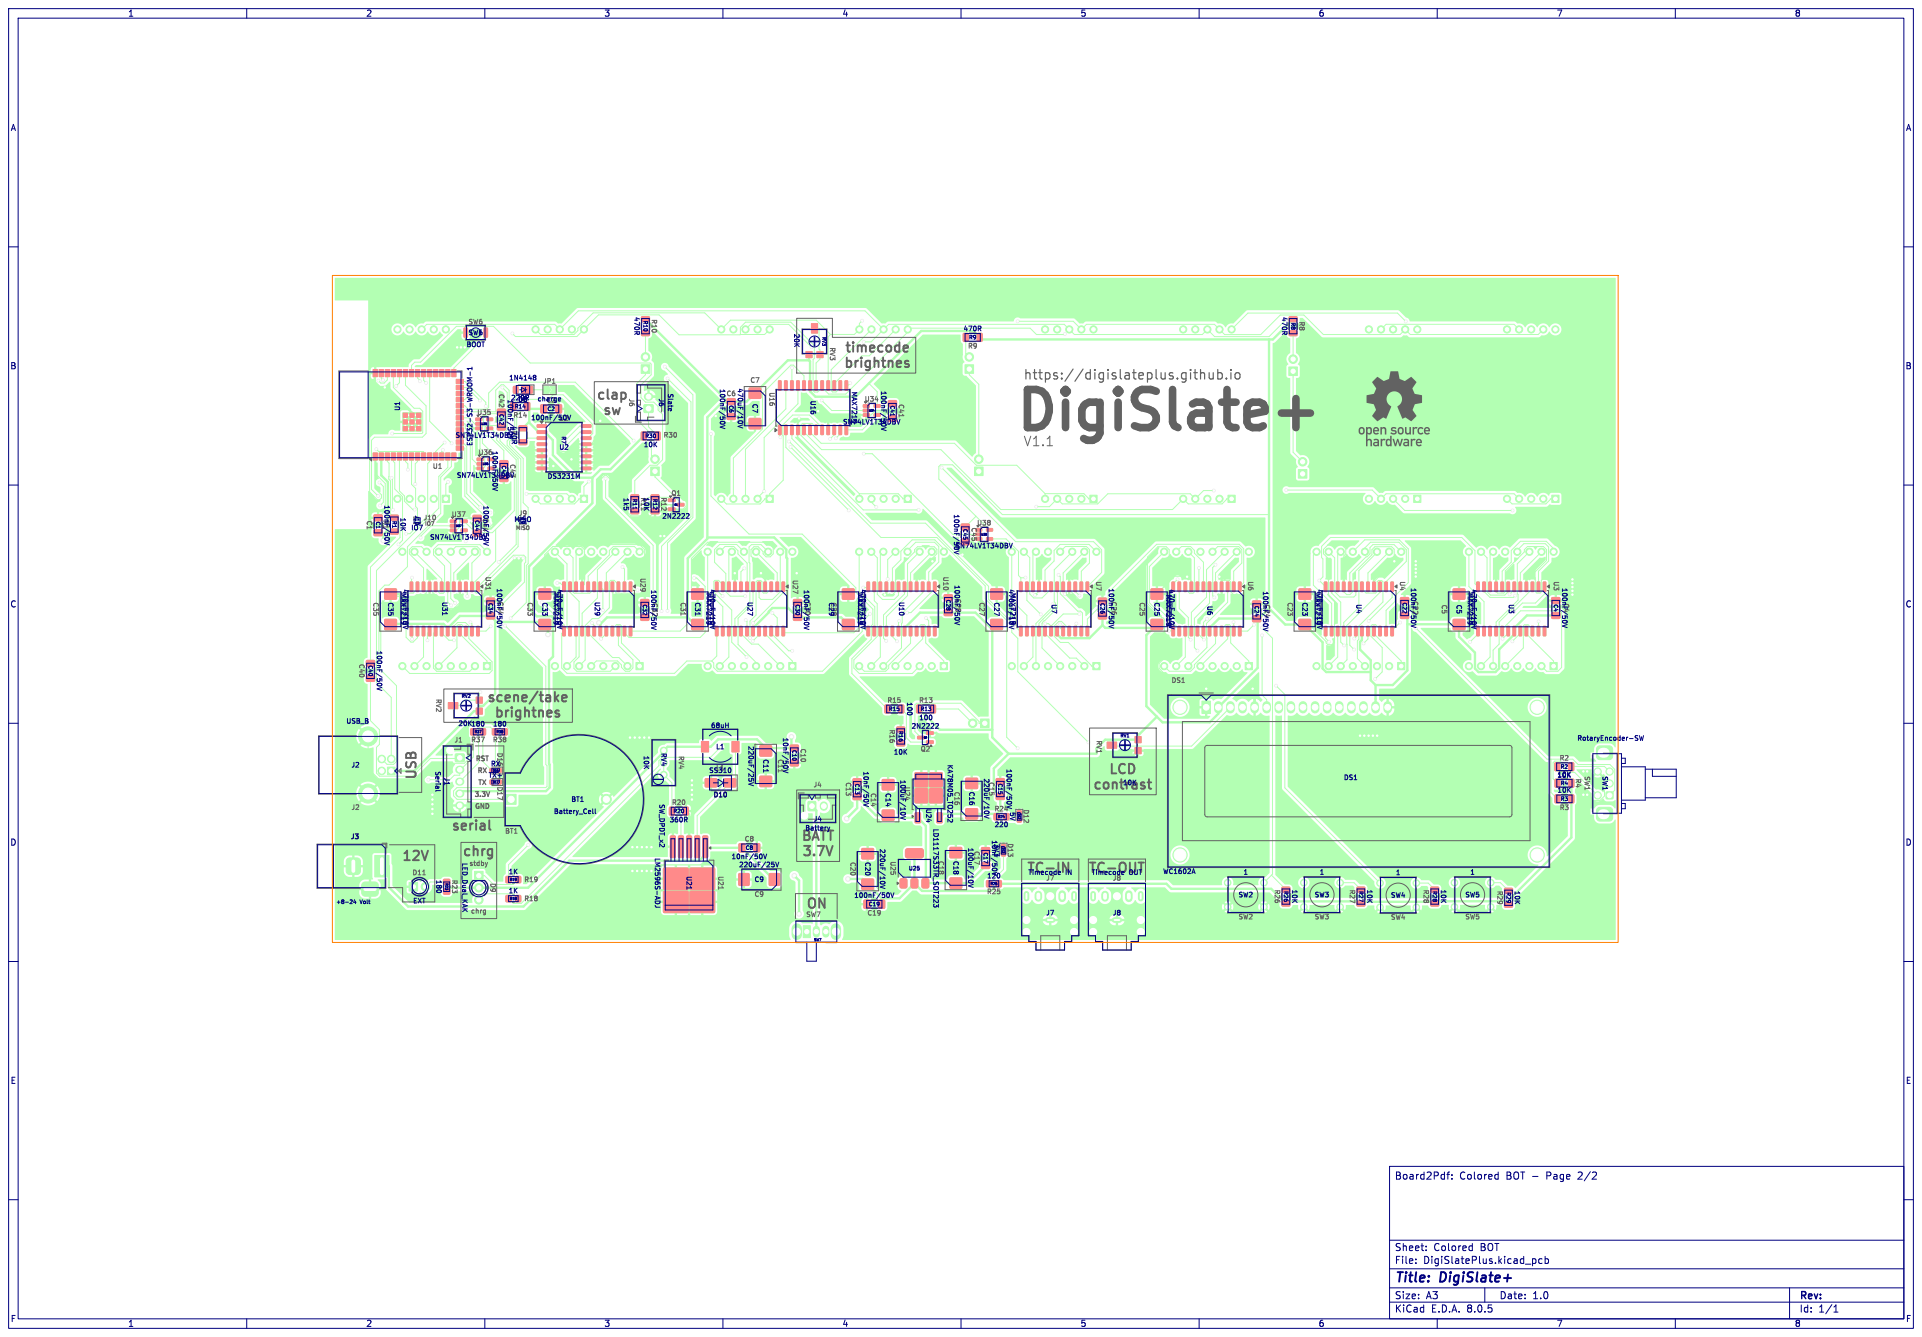
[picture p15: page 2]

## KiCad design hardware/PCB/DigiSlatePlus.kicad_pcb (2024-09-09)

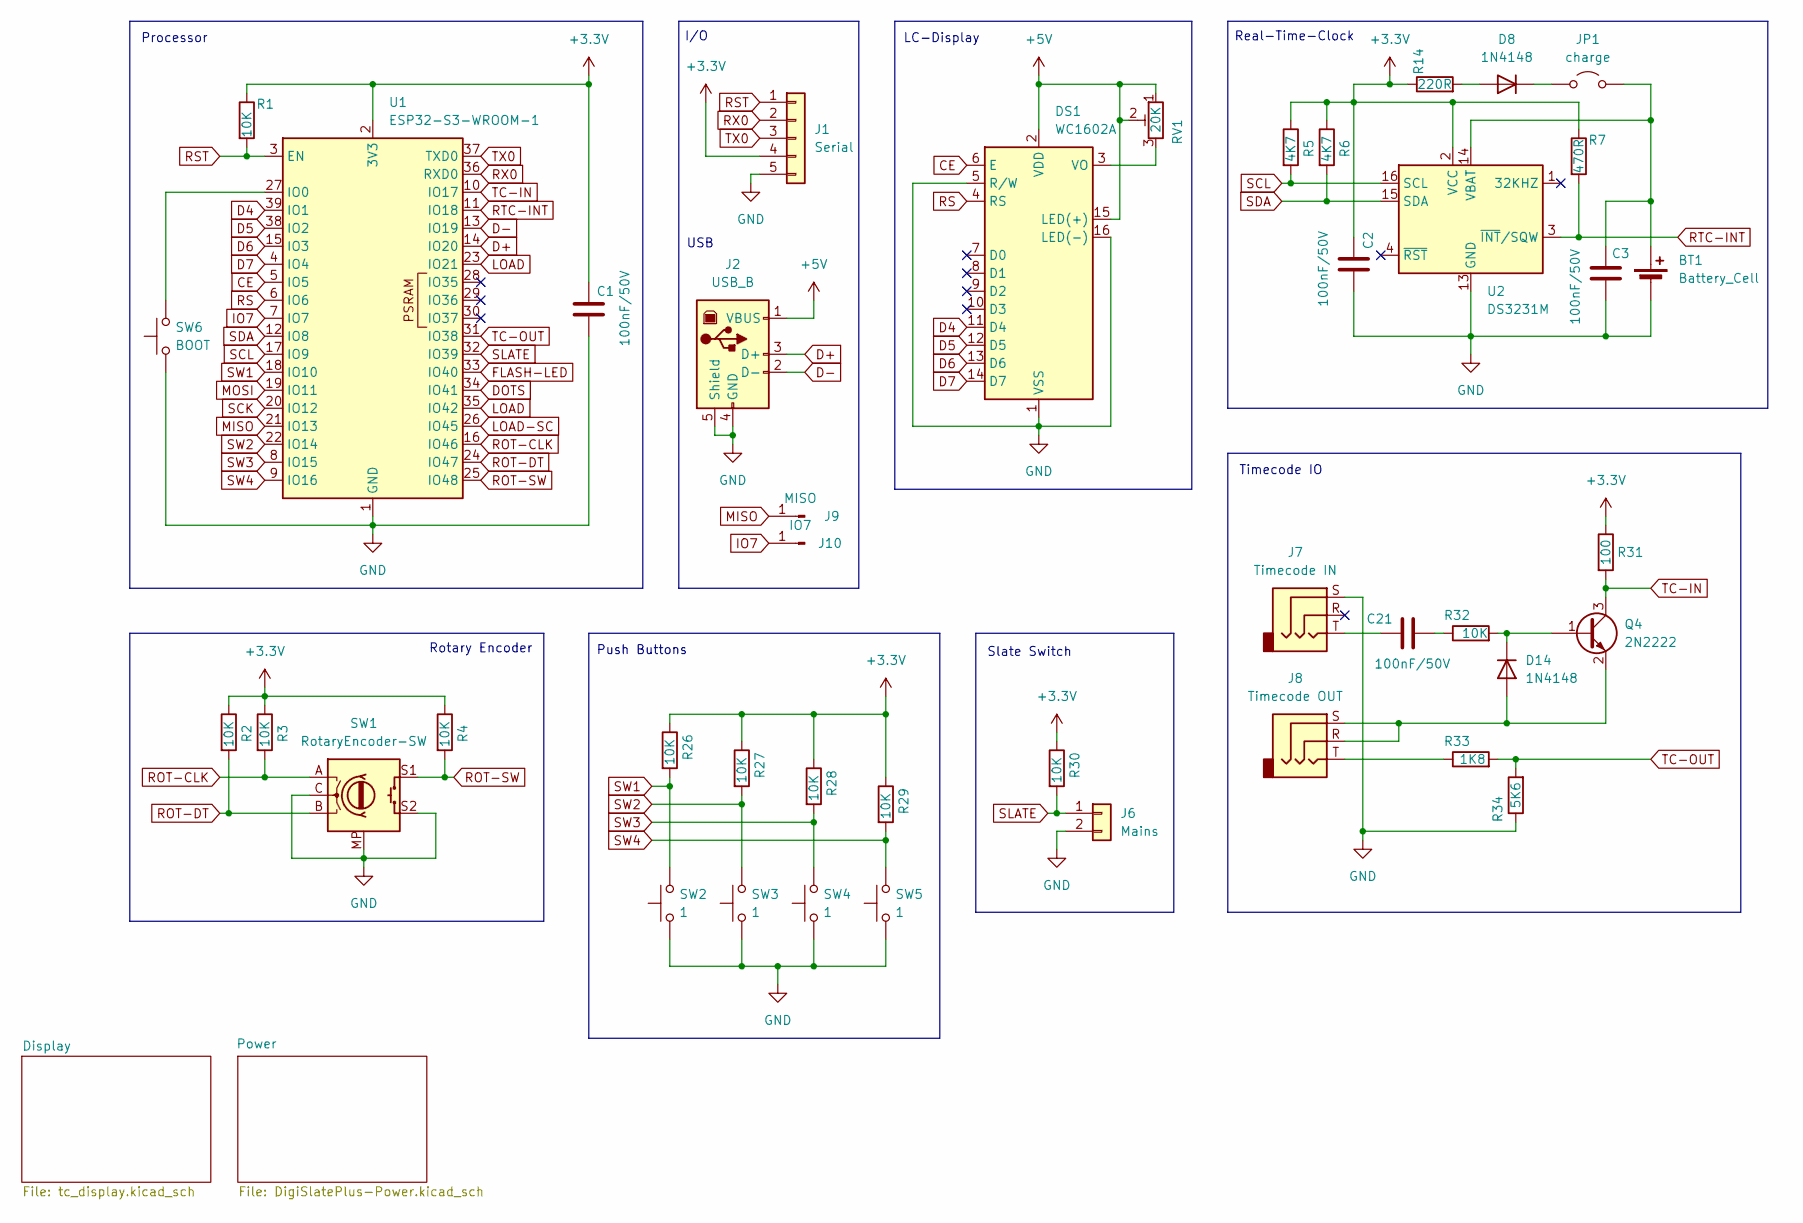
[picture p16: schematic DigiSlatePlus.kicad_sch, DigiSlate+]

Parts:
BT1: Battery_Cell; BatteryHolder_ComfortableElectronic_CH273-2450_1x2450
C1, C2, C3, C21: 100nF/50V; C_1206_3216Metric_Pad1.33x1.80mm_HandSolder
D8, D14: 1N4148; D_PowerDI-123
DS1: WC1602A
J1: Serial; JST_XH_B5B-XH-AM_1x05_P2.50mm_Vertical
J2: USB_B; USB_B_Lumberg_2411_02_Horizontal
J6: Mains; JST_XH_B2B-XH-AM_1x02_P2.50mm_Vertical
J7: Timecode IN; Jack_3.5mm_CUI_SJ1-3525N_Horizontal
J8: Timecode OUT; Jack_3.5mm_CUI_SJ1-3525N_Horizontal
J9: MISO; PinHeader_1x01_P1.00mm_Vertical
J10: IO7; PinHeader_1x01_P1.00mm_Vertical
JP1: charge; SolderJumper-2_P1.3mm_Open_TrianglePad1.0x1.5mm
Q4: 2N2222; SOT-23
R1, R2, R3, R4, R26, R27, R28, R29, R30, R32: 10K; R_1206_3216Metric
R5, R6: 4K7; R_1206_3216Metric
R7: 470R; R_1206_3216Metric
R14: 220R; R_1206_3216Metric
R31: 100; R_1206_3216Metric
R33: 1K8; R_1206_3216Metric
R34: 5K6; R_1206_3216Metric
RV1: 20K; Potentiometer_Vishay_TS53YL_Vertical
SW1: RotaryEncoder-SW; RotaryEncoder_Bourns_Horizontal_PEC12R-2x17F-Sxxxx
SW2, SW3, SW4, SW5: 1; SW_Tactile_Straight_KSA0Axx1LFTR
SW6: BOOT; SW_Push_SPST_NO_Alps_SKRK
U1: ESP32-S3-WROOM-1
U2: DS3231M; SOIC-16W_7.5x10.3mm_P1.27mm

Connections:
+5V: DS1.2 (VDD), DS1.15 (LED(+)), J2.1 (VBUS), RV1.1, RV1.2; also elsewhere on the board
CE: DS1.6 (E), U1.5 (IO5)
D4: DS1.11 (D4), U1.39 (IO1)
D5: DS1.12 (D5), U1.38 (IO2)
D6: DS1.13 (D6), U1.15 (IO3)
D7: DS1.14 (D7), U1.4 (IO4)
D+: J2.3 (D+), U1.14 (IO20)
D-: J2.2 (D-), U1.13 (IO19)
DOTS: U1.34 (IO41); also elsewhere on the board
FLASH-LED: U1.33 (IO40); also elsewhere on the board
GND: BT1.2 (-), C1.2, C2.2, C3.2, DS1.1 (VSS), DS1.5 (R/W), DS1.16 (LED(-)), J1.5, J2.4 (GND), J2.5 (Shield), J6.2, J7.S, R34.1, SW1.C, SW1.MP, SW1.S2, SW1.SH, SW2.1, SW3.1, SW4.1, SW5.1, SW6.1, U1.1 (GND), U1.40 (GND), U1.41 (GND), U2.5 (GND), U2.6 (GND), U2.7 (GND), U2.8 (GND), U2.9 (GND), U2.10 (GND), U2.11 (GND), U2.12 (GND), U2.13 (GND); also elsewhere on the board
IO7: J10.1, U1.7 (IO7)
LOAD: U1.23 (IO21), U1.35 (IO42); also elsewhere on the board
LOAD-SC: U1.26 (IO45); also elsewhere on the board
MISO: J9.1, U1.21 (IO13)
MOSI: U1.19 (IO11); also elsewhere on the board
unnamed: BT1.1 (+), C3.1, JP1.2 (B), U2.14 (VBAT)
unnamed: C21.1, J7.T
unnamed: C21.2, R32.1
unnamed: D8.2 (A), R14.2
unnamed: D8.1 (K), JP1.1 (A)
unnamed: D14.2 (A), J8.R, J8.S, Q4.2 (E)
unnamed: D14.1 (K), Q4.1 (B), R32.2
unnamed: DS1.3 (VO), RV1.3
unnamed: J8.T, R33.1
unnamed: SW6.2, U1.27 (IO0)
ROT-CLK: R3.2, SW1.A, U1.16 (IO46)
ROT-DT: R2.2, SW1.B, U1.24 (IO47)
ROT-SW: R4.2, SW1.S1, U1.25 (IO48)
RS: DS1.4 (RS), U1.6 (IO6)
RST: J1.1, R1.2, U1.3 (EN)
RTC-INT: R7.2, U1.11 (IO18), U2.3 (~INT/SQW)
RX0: J1.2, U1.36 (RXD0)
SCK: U1.20 (IO12); also elsewhere on the board
SCL: R5.2, U1.17 (IO9), U2.16 (SCL)
SDA: R6.2, U1.12 (IO8), U2.15 (SDA)
SLATE: J6.1, R30.2, U1.32 (IO39)
SW1: R26.2, SW2.2, U1.18 (IO10)
SW2: R27.2, SW3.2, U1.22 (IO14)
SW3: R28.2, SW4.2, U1.8 (IO15)
SW4: R29.2, SW5.2, U1.9 (IO16)
TC-IN: Q4.3 (C), R31.2, U1.10 (IO17)
TC-OUT: R33.2, R34.2, U1.31 (IO38)
TX0: J1.3, U1.37 (TXD0)

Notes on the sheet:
Real-Time-Clock
Push Buttons
Timecode IO
I/O
USB
Rotary Encoder
Slate Switch
LC-Display
Processor

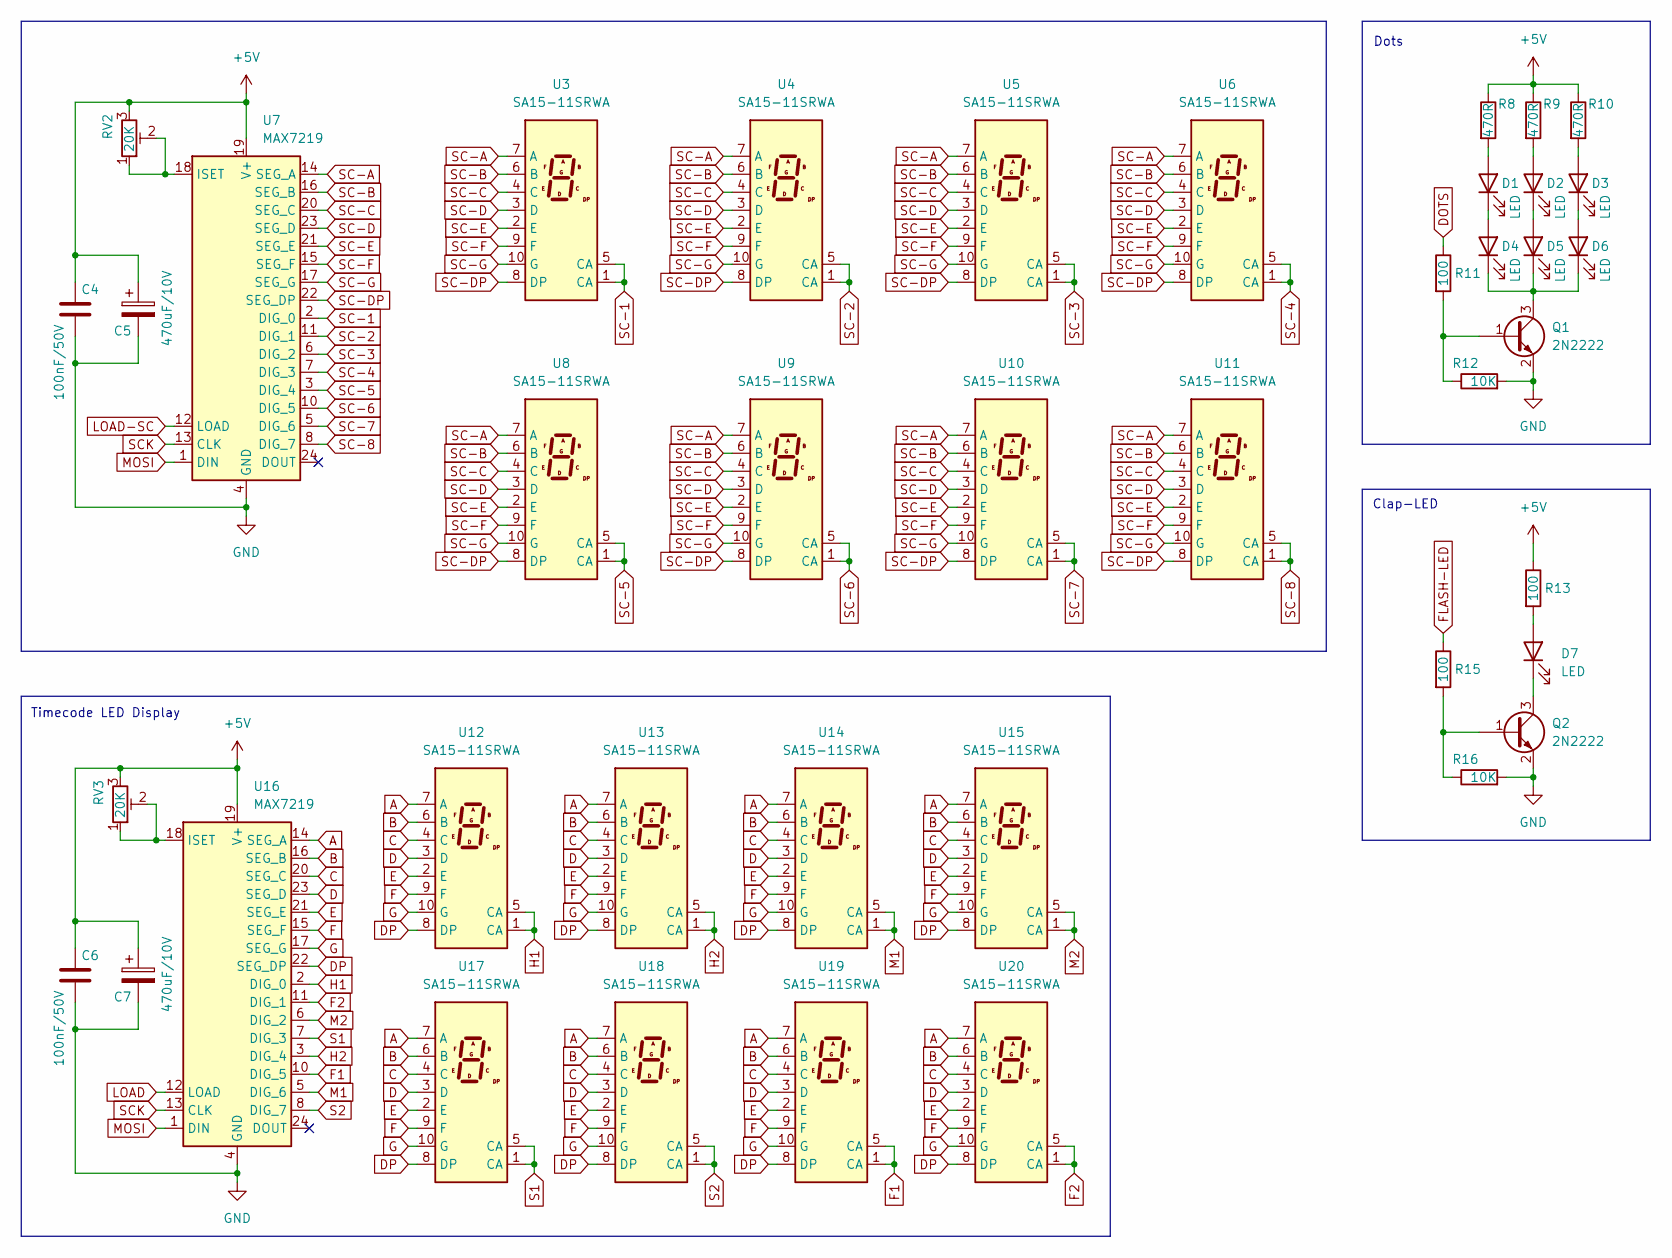
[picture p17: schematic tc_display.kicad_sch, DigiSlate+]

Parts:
C4, C6: 100nF/50V; C_1206_3216Metric_Pad1.33x1.80mm_HandSolder
C5, C7: 470uF/10V; CP_EIA-7343-31_Kemet-D_Pad2.25x2.55mm_HandSolder
D1, D2, D3, D4, D5, D6: LED; LED_D3.0mm_FlatTop
D7: LED; LED_D10.0mm
Q1, Q2: 2N2222; SOT-23
R8, R9, R10: 470R; R_1206_3216Metric
R11, R13, R15: 100; R_1206_3216Metric
R12, R16: 10K; R_1206_3216Metric
RV2, RV3: 20K; Potentiometer_Vishay_TS53YL_Vertical
U3, U4, U5, U6, U8, U9, U10, U11, U12, U13, U14, U15, U17, U18, U19, U20: SA15-11SRWA; FYS-12011A
U7, U16: MAX7219; SOIC-24W_7.5x15.4mm_P1.27mm

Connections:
+5V: C4.1, C5.1, C6.1, C7.1, R8.1, R9.1, R10.1, R13.1, RV2.3, RV3.3, U7.19 (V+), U16.19 (V+); also elsewhere on the board
A: U12.7 (A), U13.7 (A), U14.7 (A), U15.7 (A), U16.14 (SEG_A), U17.7 (A), U18.7 (A), U19.7 (A), U20.7 (A)
B: U12.6 (B), U13.6 (B), U14.6 (B), U15.6 (B), U16.16 (SEG_B), U17.6 (B), U18.6 (B), U19.6 (B), U20.6 (B)
C: U12.4 (C), U13.4 (C), U14.4 (C), U15.4 (C), U16.20 (SEG_C), U17.4 (C), U18.4 (C), U19.4 (C), U20.4 (C)
D: U12.3 (D), U13.3 (D), U14.3 (D), U15.3 (D), U16.23 (SEG_D), U17.3 (D), U18.3 (D), U19.3 (D), U20.3 (D)
DOTS: R11.1; also elsewhere on the board
DP: U12.8 (DP), U13.8 (DP), U14.8 (DP), U15.8 (DP), U16.22 (SEG_DP), U17.8 (DP), U18.8 (DP), U19.8 (DP), U20.8 (DP)
E: U12.2 (E), U13.2 (E), U14.2 (E), U15.2 (E), U16.21 (SEG_E), U17.2 (E), U18.2 (E), U19.2 (E), U20.2 (E)
F: U12.9 (F), U13.9 (F), U14.9 (F), U15.9 (F), U16.15 (SEG_F), U17.9 (F), U18.9 (F), U19.9 (F), U20.9 (F)
F1: U16.10 (DIG_5), U19.1 (CA), U19.5 (CA)
F2: U16.11 (DIG_1), U20.1 (CA), U20.5 (CA)
FLASH-LED: R15.1; also elsewhere on the board
G: U12.10 (G), U13.10 (G), U14.10 (G), U15.10 (G), U16.17 (SEG_G), U17.10 (G), U18.10 (G), U19.10 (G), U20.10 (G)
GND: C4.2, C5.2, C6.2, C7.2, Q1.2 (E), Q2.2 (E), R12.2, R16.2, U7.4 (GND), U7.9 (GND), U16.4 (GND), U16.9 (GND); also elsewhere on the board
H1: U12.1 (CA), U12.5 (CA), U16.2 (DIG_0)
H2: U13.1 (CA), U13.5 (CA), U16.3 (DIG_4)
LOAD: U16.12 (LOAD); also elsewhere on the board
LOAD-SC: U7.12 (LOAD); also elsewhere on the board
M1: U14.1 (CA), U14.5 (CA), U16.5 (DIG_6)
M2: U15.1 (CA), U15.5 (CA), U16.6 (DIG_2)
MOSI: U7.1 (DIN), U16.1 (DIN); also elsewhere on the board
unnamed: D1.2 (A), R8.2
unnamed: D1.1 (K), D4.2 (A)
unnamed: D2.2 (A), R9.2
unnamed: D2.1 (K), D5.2 (A)
unnamed: D3.2 (A), R10.2
unnamed: D3.1 (K), D6.2 (A)
unnamed: D4.1 (K), D5.1 (K), D6.1 (K), Q1.3 (C)
unnamed: D7.2 (A), R13.2
unnamed: D7.1 (K), Q2.3 (C)
unnamed: Q1.1 (B), R11.2, R12.1
unnamed: Q2.1 (B), R15.2, R16.1
unnamed: RV2.1, RV2.2, U7.18 (ISET)
unnamed: RV3.1, RV3.2, U16.18 (ISET)
S1: U16.7 (DIG_3), U17.1 (CA), U17.5 (CA)
S2: U16.8 (DIG_7), U18.1 (CA), U18.5 (CA)
SC-1: U3.1 (CA), U3.5 (CA), U7.2 (DIG_0)
SC-2: U4.1 (CA), U4.5 (CA), U7.11 (DIG_1)
SC-3: U5.1 (CA), U5.5 (CA), U7.6 (DIG_2)
SC-4: U6.1 (CA), U6.5 (CA), U7.7 (DIG_3)
SC-5: U7.3 (DIG_4), U8.1 (CA), U8.5 (CA)
SC-6: U7.10 (DIG_5), U9.1 (CA), U9.5 (CA)
SC-7: U7.5 (DIG_6), U10.1 (CA), U10.5 (CA)
SC-8: U7.8 (DIG_7), U11.1 (CA), U11.5 (CA)
SC-A: U3.7 (A), U4.7 (A), U5.7 (A), U6.7 (A), U7.14 (SEG_A), U8.7 (A), U9.7 (A), U10.7 (A), U11.7 (A)
SC-B: U3.6 (B), U4.6 (B), U5.6 (B), U6.6 (B), U7.16 (SEG_B), U8.6 (B), U9.6 (B), U10.6 (B), U11.6 (B)
SC-C: U3.4 (C), U4.4 (C), U5.4 (C), U6.4 (C), U7.20 (SEG_C), U8.4 (C), U9.4 (C), U10.4 (C), U11.4 (C)
SC-D: U3.3 (D), U4.3 (D), U5.3 (D), U6.3 (D), U7.23 (SEG_D), U8.3 (D), U9.3 (D), U10.3 (D), U11.3 (D)
SC-DP: U3.8 (DP), U4.8 (DP), U5.8 (DP), U6.8 (DP), U7.22 (SEG_DP), U8.8 (DP), U9.8 (DP), U10.8 (DP), U11.8 (DP)
SC-E: U3.2 (E), U4.2 (E), U5.2 (E), U6.2 (E), U7.21 (SEG_E), U8.2 (E), U9.2 (E), U10.2 (E), U11.2 (E)
SC-F: U3.9 (F), U4.9 (F), U5.9 (F), U6.9 (F), U7.15 (SEG_F), U8.9 (F), U9.9 (F), U10.9 (F), U11.9 (F)
SC-G: U3.10 (G), U4.10 (G), U5.10 (G), U6.10 (G), U7.17 (SEG_G), U8.10 (G), U9.10 (G), U10.10 (G), U11.10 (G)
SCK: U7.13 (CLK), U16.13 (CLK); also elsewhere on the board

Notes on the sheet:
Timecode LED Display
Dots
Clap-LED

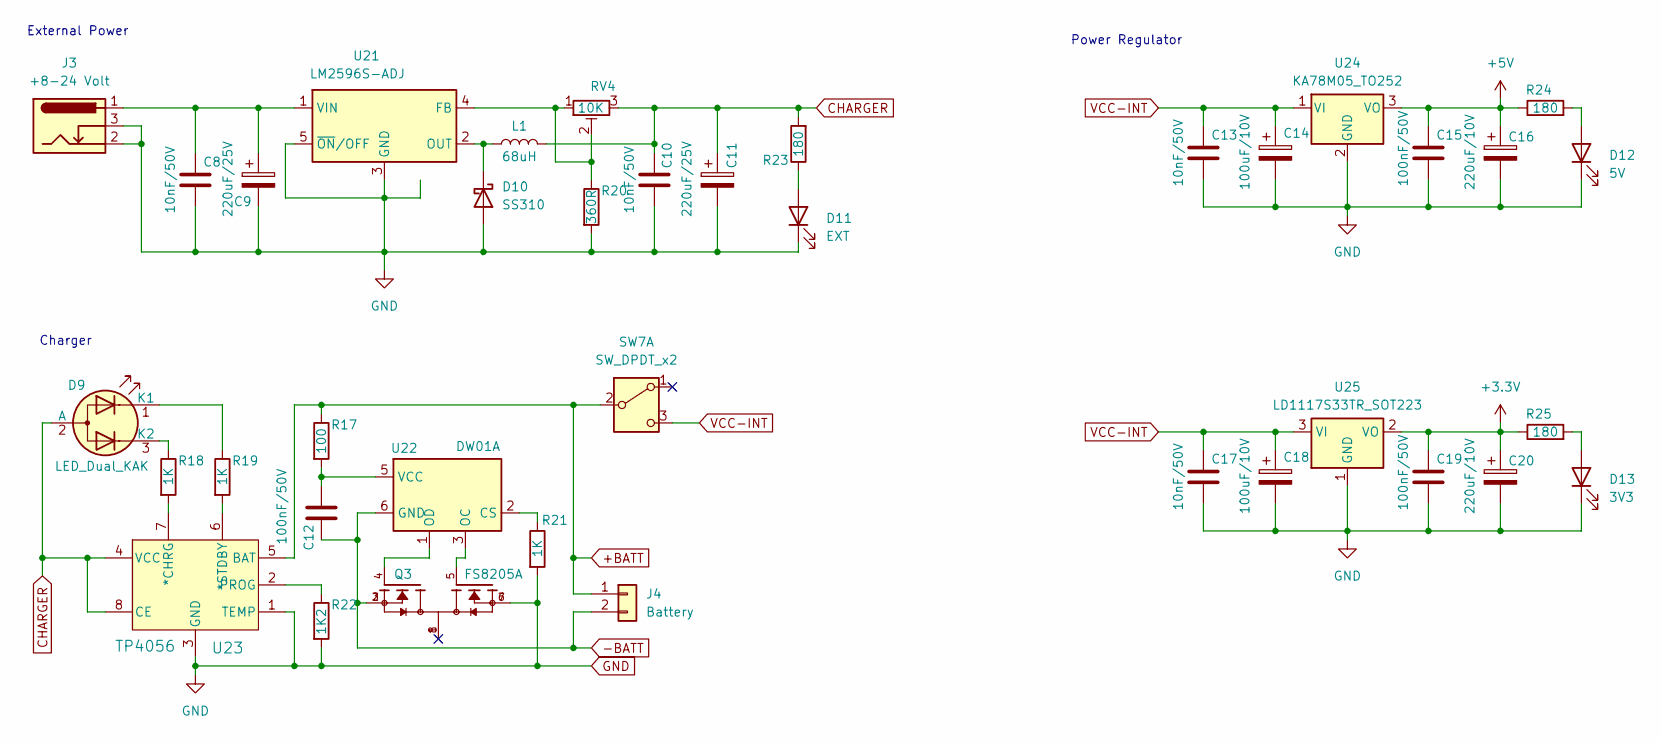
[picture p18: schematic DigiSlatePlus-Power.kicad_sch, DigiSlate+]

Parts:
C8, C10, C13, C17: 10nF/50V; C_1206_3216Metric_Pad1.33x1.80mm_HandSolder
C9, C11: 220uF/25V; CP_EIA-7343-31_Kemet-D_Pad2.25x2.55mm_HandSolder
C12, C15, C19: 100nF/50V; C_1206_3216Metric_Pad1.33x1.80mm_HandSolder
C14, C18: 100uF/10V; CP_EIA-7343-31_Kemet-D_Pad2.25x2.55mm_HandSolder
C16, C20: 220uF/10V; CP_EIA-7343-31_Kemet-D_Pad2.25x2.55mm_HandSolder
D9: LED_Dual_KAK; LED_D3.0mm-3
D10: SS310; D_SMA
D11: EXT; LED_D3.0mm
D12: 5V; LED_0603_1608Metric
D13: 3V3; LED_0603_1608Metric
J3: +8-24 Volt; BarrelJack_GCT_DCJ200-10-A_Horizontal
J4: Battery; JST_XH_B2B-XH-AM_1x02_P2.50mm_Vertical
L1: 68uH; L_7.3x7.3_H3.5
Q3: FS8205A; TSSOP-8_3x3mm_P0.65mm; PARTREV 1.7
R17: 100; R_1206_3216Metric
R18, R19, R21: 1K; R_0805_2012Metric_Pad1.20x1.40mm_HandSolder
R20: 360R; R_1206_3216Metric
R22: 1K2; R_0805_2012Metric_Pad1.20x1.40mm_HandSolder
R23, R24, R25: 180; R_0805_2012Metric_Pad1.20x1.40mm_HandSolder
RV4: 10K; Potentiometer_Bourns_3296W_Vertical
SW7: SW_DPDT_x2; SW_Slide_SPDT_Angled_CK_OS102011MA1Q
U21: LM2596S-ADJ; TO-263-5_TabPin3
U22: DW01A; SOT-23-6
U23: TP4056; TP4056-42-ESOP8_TPW
U24: KA78M05_TO252; TO-252-2
U25: LD1117S33TR_SOT223; SOT-223-3_TabPin2

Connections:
+5V: C15.1, C16.1, R24.1, U24.3 (VO); also elsewhere on the board
+BATT: J4.1, R17.1, SW7.2 (B), U23.5 (BAT)
-BATT: C12.1, J4.2, Q3.2, Q3.3, U22.6 (GND)
CHARGER: C10.1, C11.1, D9.2 (A), L1.2, R23.2, RV4.3, U23.4 (VCC), U23.8 (CE)
GND: C8.2, C9.2, C10.2, C11.2, C13.2, C14.2, C15.2, C16.2, C17.2, C18.2, C19.2, C20.2, D10.2 (A), D11.1 (K), D12.1 (K), D13.1 (K), J3.2, J3.3, Q3.6, Q3.7, R20.2, R21.2, R22.2, U21.3 (GND), U21.5 (~ON/OFF), U23.1 (TEMP), U23.3 (GND), U24.2 (GND), U25.1 (GND); also elsewhere on the board
unnamed: D9.1 (K1), R19.1
unnamed: D9.3 (K2), R18.1
unnamed: D10.1 (K), L1.1, U21.2 (OUT)
unnamed: D11.2 (A), R23.1
unnamed: D12.2 (A), R24.2
unnamed: D13.2 (A), R25.2
unnamed: R20.1, RV4.1, RV4.2, U21.4 (FB)
unnamed: C8.1, C9.1, J3.1, U21.1 (VIN)
unnamed: R21.1, U22.2 (CS)
unnamed: Q3.5, U22.3 (OC)
unnamed: Q3.4, U22.1 (OD)
unnamed: C12.2, R17.2, U22.5 (VCC)
unnamed: R18.2, U23.7 (*CHRG)
unnamed: R19.2, U23.6 (*STDBY)
unnamed: R22.1, U23.2 (PROG)

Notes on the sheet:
Power Regulator
External Power
Charger

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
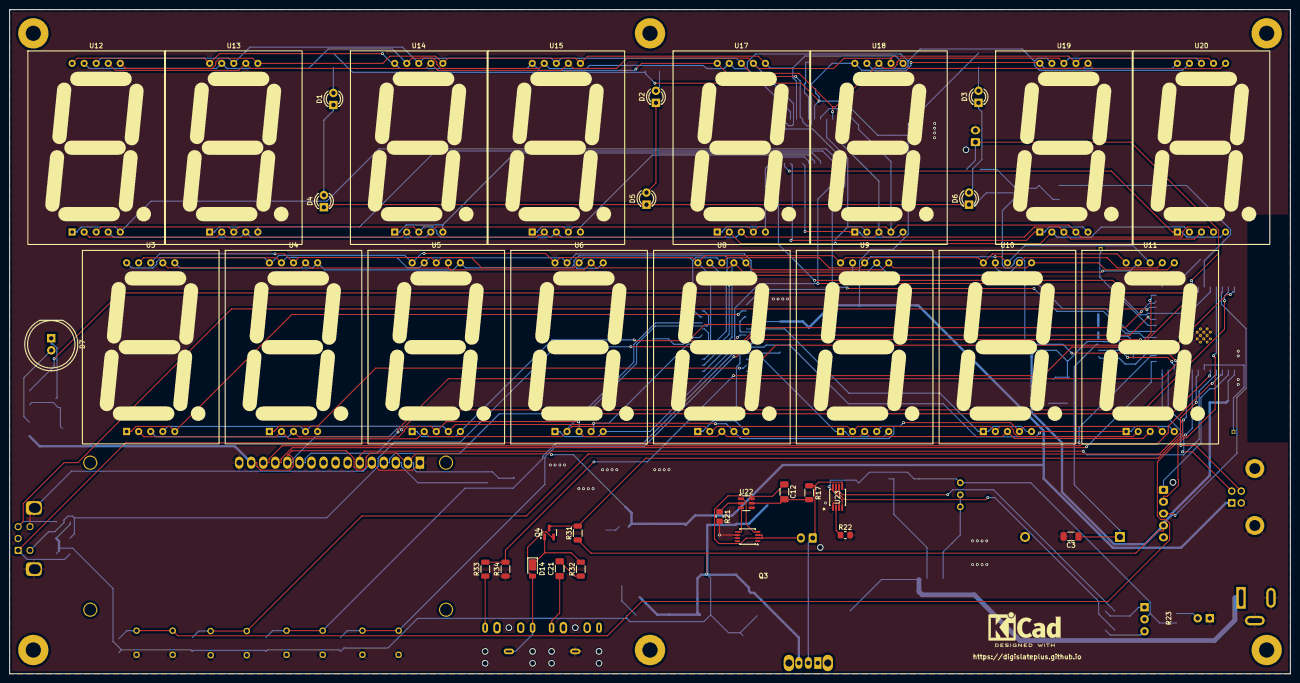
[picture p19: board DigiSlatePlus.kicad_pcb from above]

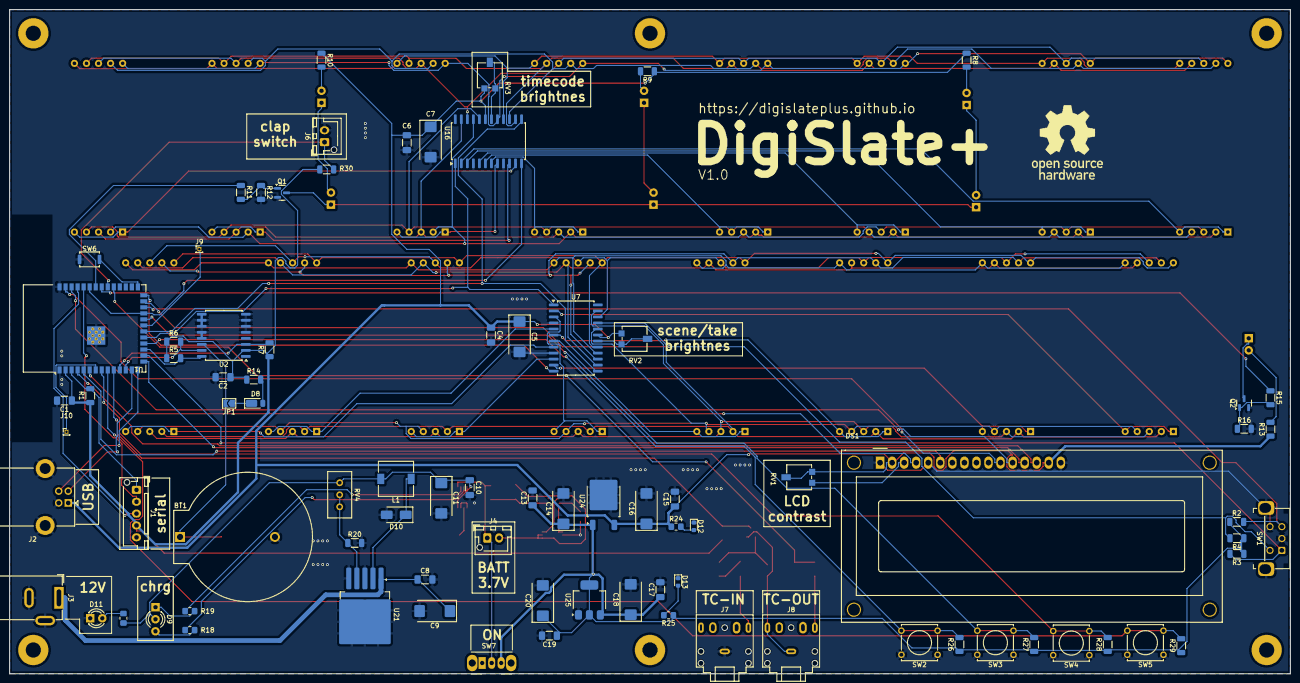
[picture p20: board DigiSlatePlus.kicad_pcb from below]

Board: 2 copper layers, 270.0 x 140.0 mm, 129 parts (85 on the bottom side), 108 nets.

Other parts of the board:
Hole1, Hole2, Hole3, Hole4, Hole5, Hole6: MountingHole_3.2mm_M3_Pad
OHW-Logo: LOGO; Open-Source-Hardware-Logo

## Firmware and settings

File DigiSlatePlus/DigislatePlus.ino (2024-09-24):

/*
 DigiSlatePlus
 */

/*
This Source Code Form is subject to the terms of the
Mozilla Public License, v. 2.0. If a copy of the MPL was not distributed
with this file, You can obtain one at http://mozilla.org/MPL/2.0/.

Copyright (c) 2024 Thomas Winkler

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
THE SOFTWARE IS PROVIDED "AS IS", WITHOUT WARRANTY OF ANY KIND,
EXPRESS OR IMPLIED, INCLUDING BUT NOT LIMITED TO THE WARRANTIES OF
MERCHANTABILITY, FITNESS FOR A PARTICULAR PURPOSE AND NONINFRINGEMENT.
IN NO EVENT SHALL THE AUTHORS OR COPYRIGHT HOLDERS BE LIABLE FOR ANY CLAIM,
DAMAGES OR OTHER LIABILITY, WHETHER IN AN ACTION OF CONTRACT, TORT OR
OTHERWISE, ARISING FROM, OUT OF OR IN CONNECTION WITH THE SOFTWARE OR THE USE
OR OTHER DEALINGS IN THE SOFTWARE.
*/


/*
 The DigiSlatePlus creates timecode synchronized with a
 DS3231 high precision RTC clock and sent to the 3,5mm Jack.

 The time is set by maintaining a LTC timecode to the input
 and powering up the slate. The RTC time is set according
 to the provided timecode.
 !!! (NOT YET IMPLEMENTED)

 When no timecode is found on the BNC connector, the internal
 generated timecode is displayed and available on the BNC.
 */


/* Adaptive SMPTE/EBU LTC Reader

	based on code by Jim Mack
			Editing Services Co.
			esc@mdxi.com

	 Reads LTC (audio timecode) on pin 2, at any common
		frame rate and at any speed from about 1/10x to 5x
		play, in forward or reverse.

	 Proper reading requires a good quality signal and
		conditioning. A simple booster will often be
		enough to read consumer-level signals. A schematic
		for a simple input stage is shown in the blog post.

	 This code will have less success tracking sources with
		high compression or generation loss. Better audio =
		better results, especially at higher speeds.
*/


/*
 FLOAT
 
 setup()
	1. init classes and variables
	2. start LED and LC displays and clap flash LED
	3. init timecode structure
	4. init real time clock
	5. init interrupts
		a. init reader class
		b. attach interrupts

 loop()
	1. get clapbar switch
	
	is RUNMODE
		1. IF boot or runmode did not change
			a. read time from rtc and write to timecode
			b. set framerate
		2.	IF timecode has changed
			a. check clapbar and flash light
			b. display timecode on LED if running (not just clapped)
			c. IF tick (interrupt from RTC occured)
				recalculate bit timer for tc output
		3. display status (run, clap, init) on LCD

	is READMODE
		1. check for read timeout > set to runmode
		2. IF boot or mode changed
			a. set mode to READMODE
		3. diable timecode
		4. IF reader synced
			a. IF value available
				> get reader timecode
				> display on LED
				> IF framerate changed
					* display fps on LCD
				> IF read boot
					* display status jam on LCD

					* IF rtc not updated
						> get date from rtc
						> write read time to RTC
						> set rtc updated true

				> ELSE display status sync on LCD
		5. ELSE display status read on LCD

 */

/*
 dependencies

 RTCLIB.h 			by Adafruit / fork of Jeelab's RTC library Version 2.1.4
 LiquidCrystal.h 	by Arduino Version 1.0.7
 LedControl			https://github.com/wayoda/LedControl
 */



#include <Arduino.h>
#include <RTClib.h>

#include "setup.h"

#include "lcd.h"
#include "led.h"
#include "rled.h"
#include "tc.h"
#include "rtc.h"
#include "reader.h"
#include "flash.h"
#include "settings.h"
#include "button.h"


// =========================================
// init classes
LCD lcd;
LED led;
RLED rled;
TC tc;
RTC rtc;
READER reader;
FLASH flash;
BUTTON button;

TC reader_tc;


bool clap;
bool run;
uint32_t claptime;
uint32_t old_claptime;


// =========================================
// timecode timing
long realtime;
long old_realtime;
long cycletime;

long timertime;
long lastreadtime;

bool tick;


// DEBUG
long offset;


// =========================================
// run mode
// 		RUNMODE => free run mode
// 		READMODE => read mode
bool runMode;
bool lastRunMode;

bool boot;				// true on system start
bool rtc_updated;		// false on system start

#include <EEPROM.h>

// =========================================
void setup() {



	// set initial state
	// set initial state to readmode
	runMode = READMODE;
	lastRunMode = runMode;

	boot = true;
	rtc_updated = false;

	clap = false;


	// start timing
	realtime = micros();
	old_realtime = realtime;


	// =============================================================
	// INIT IO
	pinMode(SIGNAL_OUTPUT,OUTPUT);
	button.begin(BUTTON_PORT);


	// =============================================================
	// INIT flash led
	rled.begin(FLASH_LED);
	rled.on();


	// =============================================================
	// INIT LC-Display
	lcd.begin(LCD_RS, LCD_EN, LCD_D4, LCD_D5, LCD_D6, LCD_D7);


	lcd.print(" DigiSlate-Plus", 0, 0);
	lcd.print("  initializing", 0, 1);


	// =============================================================
	// INIT LED-Display
	led.begin(LOAD_PIN);


	// test LED display
	led.set(88, 88, 88, 88);
	delay(500);


	// =============================================================
	// start real time clock
	switch (rtc.begin(RTC_INT_PORT)) {

		case 1:
			lcd.status(" RTC");

			break;

		case 0:
			lcd.status("!RTC");
			break;

		case -1:
			lcd.status(" SET");
			break; 
	}


	// =============================================================
	// INIT timecode
	tc.begin();
	tc.set(0,0,0,0);


	// =============================================================
	// check for setup
	lcd.clear();
	lcd.print("  Tripple clap", 0, 0);
	lcd.print(" to enter setup", 0, 1);


	SETTINGS settings;

	if (settings.begin(&button, &lcd, &led)) {
		settings.exec();
	}


	// =============================================================
	// INIT flash
	// get data from EEPROM
	flash.begin();
	TIMECODE flash_tc = flash.read();


	// framerate is not valid > load default values and write to flash
	if (!in_array(flash_tc.fps, framerates, 3)) {

		tc.fps((uint8_t)DEFAULT_FRAMERATE);
		tc.flags(0);

		lcd.clear();
		lcd.print("No flash values!", 0, 0);
		lcd.print("  load default", 0, 1);

		flash.write(tc.get());
		flash.write_userbits(tc.ubits());

		delay(1000);
	}


	// set found framerate
	else {
		tc.fps(flash_tc.fps);
	}


	// display timecode on LED
	led.set(tc.get());


	// =============================================================
	// end INIT sequence
	rled.off();
	lcd.clear();


	// =============================================================
	// activate interrupts
	pinMode(RTC_INT_PORT, INPUT_PULLUP);  	// rtc sync input


	// start reader class
	reader.begin(SIGNAL_INPUT);

	tick = false;

	cli();
	attachInterrupt(digitalPinToInterrupt(SIGNAL_INPUT), readISR, CHANGE);
	attachInterrupt(digitalPinToInterrupt(RTC_INT_PORT), syncISR, FALLING);
	sei();


	start_timer1(tc.fps());
}


// =========================================
//
void loop() {

	// get clapbar state
	// true = closed
	bool clapbar = !button.get();


	// =============================================================
	// =============================================================
	// free run mode
	// no TC on input
	// =============================================================
	// =============================================================
	if (runMode == RUNMODE) {


		// ===================================
		// mode changed to runMode
		if (boot || (runMode != lastRunMode)) {

			lcd.clear();

			lastRunMode = runMode;
			boot = false;
			rtc_updated = false;

			// init runMode
			// read rtc and set time code
			if (rtc.status() != false) {

				// init time of slate to rtc
				DateTime time = rtc.get();
				tc.set(time.hour(), time.minute(), time.second(), 0);

				// set date in user bits
				// tc.ubits((time.year() / 1000) & 0xF, (time.year() / 100) & 0xF, (time.year() % 100) & 0xF, (time.month() / 10) & 0xF, (time.month() % 10) & 0xF, (time.day() / 10) & 0xF, (time.day() % 10) & 0xF);

				// snprintf("%0d:%0d:%0d", tc.ubit[0], tc.ubit[2], tc.ubit[3]);

				// display date as userbits on LCD
		// DEBUG uncomment for second row display
				// lcd.val8(time.day(), 0, 1);
				// lcd.print(".", 2, 1);
				// lcd.val8(time.month(), 3, 1);
				// lcd.print(".", 5, 1);
				// lcd.val16(time.year(), 6, 1);
			}


			// ===================
			// set lc display data
			lcd.fps(tc.fps());
		}


		// =============================================================
		// slate just closed (button open)
		if (button.changed() && clapbar == true) {
			rled.flash(30);
			run = false;
		}


		// slate was closed (button open) for CLAP_LONG_CLOSED
		if (button.opened(CLAP_LONG_CLOSED)) {
			// rled.flash(30);
			run = true;
		}


		// =============================================================
		// update time if timecode has changed
		if (tc.changed()) {
			tc.unchange();


			// ===================================
			// slate is closed for CLAP_LONG_CLOSED ms
			if (run) {

				if (tc.enable()) {
					led.set(tc.get());
				}
			}

			// second started
			// correct timer every second
			if (tick) {

				tick = false;

				// =========================================
				// sync timer by rtc
				// rtc time smaller
				// speed um timer
				if (cycletime < timertime) {
					OCR1A--;
				}

				// slow down timer
				else if (cycletime > timertime) {
					OCR1A++;
				}


				// enable if different is low enough
				if (abs(cycletime - timertime) < ENABLE_LIMIT) {
					tc.enable(true);
				}
				else {
					tc.enable(false);
				}
			}
		}


		// show status
		if (tc.enable()) {

			if (run) {
				lcd.status(" run");
			}
			else {
				lcd.status("clap");
			}
		}
		else {
			lcd.status("init");
		}
	}
	// =============================================================
	// END OF RUN MODE
	// =============================================================



	// =============================================================
	// =============================================================
	// READ MODE
	// =============================================================
	// =============================================================
	else {


		// return to run mode
		if (millis() > (lastreadtime + READ_TIMEOUT)) {
			runMode = RUNMODE;

			start_timer1(tc.fps());
		}

		else {


			// mode changed to readmode
			if (boot | (runMode != lastRunMode)) {

				reader.reset();
				lastRunMode = runMode;
				lcd.clear();
			}


			// =========================================
			// disaple run timecode
			tc.enable(false);


			// check if reader is in sync
			if (reader.sync()) {

				// a timecode value is available
				if (reader.available()) {


					// get read timecode
					reader_tc.set(reader.get());

					led.set(reader_tc.get());


					// =====================
					// display new framerate
					if (reader.fps_changed()) {
						lcd.fps(reader_tc.fps() + 1);
					}


					// =======================================
					// if just booted -> write timecode to rtc
					if (boot) {
						lcd.status(" jam");
						lcd.print("offset ", 0, 1);
						lcd.val8(reader_tc.offset(), 7, 1);

						// rtc not jet updated > do it
						if (!rtc_updated) {

							// get current rtc settings
							DateTime rtc_time = rtc.get();
							DateTime new_time;

							// set new time to rtc
							rtc.set(reader_tc.get().h, reader_tc.get().m, reader_tc.get().s, rtc_time.day(), rtc_time.month(), rtc_time.year());

							// write flags to flash store
							flash.write(reader_tc.get());

							// timecode update completed
							rtc_updated = true;
						}
					}

					else {
						lcd.status("sync");
						lcd.val8(reader_tc.offset(), 0, 1);
					}
				}
			}

			// not synced
			else {
				lcd.status("read");
			}
		}

	}
	// =============================================================
	// END OF READ MODE
	// =============================================================

}

// end of loop()



// =========================================
// INTERRUPT ROUTINES
// =========================================

// start bit timer interrupt
void start_timer1(uint8_t fps) {

	// =========================================
	// 25 * 80 Hz Interrupt
	cli();

	// Clear registers
	TCCR1A = 0;
	TCCR1B = 0;
	TCNT1 = 0;

	// set inital cmr by framerate
	switch(fps) {
		case 24:
			OCR1A = TIMER_24; // 24 fpx
			break;
		case 25:
			OCR1A = TIMER_25; // 25 fps
			break;
		case 30:
			OCR1A = TIMER_30; // 30 fps
			break;
	}


	// CTC
	TCCR1B |= (1 << WGM12);
	// Prescaler 8
	TCCR1B |= (1 << CS10);
	// Output Compare Match A Interrupt Enable
	TIMSK1 |= (1 << OCIE1A);

	sei();
	// =========================================
}


// stop timer
// write 0 to clock select bits
void stop_timer1(void) {
	TCCR1B &= ~(1 << CS10);
	TCCR1B &= ~(1 << CS11);
	TCCR1B &= ~(1 << CS12);
}


// check if value is in array
// (needle, array, length)
bool in_array(uint8_t val, uint8_t* ary, uint8_t length) {

	for (uint8_t i = 0; i < length; i++) {

		if (val == ary[i]) {
			return true;
		}
	}

	return false;
}


// =========================================
// RTC interrupt every exact second
void syncISR() {

	// sync timecode frames to second start
	reader_tc.sync();

	tick = true;

	// micros for 1 second
	realtime = micros();
	cycletime = realtime - old_realtime;
	old_realtime = realtime;
}


// =========================================
// timecode read interrupt
void readISR(void) {

	// init read mode
	runMode = READMODE;
	stop_timer1();

	lastreadtime = millis();

	// read bit
	reader.read();
}


// =========================================
// timer 1 interrupt (16 bit) => 1/2 bit timecode
// framerate * 80
// timer 1
// 	24 fps => 3840 Hz; cmr = 4166
// 	25 fps => 4000 Hz; cmr = 4000
// 	30 fps => 4800 Hz; cmr = 3332
ISR(TIMER1_COMPA_vect) {

	long time;

	// tick signals the second from the rtc
	// the timecode can run in an frame offset
	timertime = tc.inc(tick);
}



/* Check for micros() rollover
if (currentMicros < lastMicros) {
elapsedMicros = (18446744073709551615ULL - lastMicros) + currentMicros + 1;
} else {
elapsedMicros = currentMicros - lastMicros;
}*/

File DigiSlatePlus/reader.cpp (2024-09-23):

#include "reader.h"


// start listening at port
void READER::begin(uint16_t port) {

	_port = port;
	pinMode(port, INPUT_PULLUP);

	// set initial threshold
	_threshold = TIMECODE_THRESHOLD;

	// sync is true if frame is available
	_sync = false;
	_reset();
	reset();

	_sync_word =  0b0011111111111101;
	_sync_register = 0;

}


// reset values
void READER::reset(void) {
	_tc.fps_change(true);
}


// ===========================================
// input value changed
bool READER::read(void) {

	long current = micros();
	long delta = current - _last_time;
	_last_time = current;

	// recalculate threshold
	// _threshold = (_threshold + delta) / 2;

	bool val = digitalRead(_port);


	// loop write to tc output if synced
	// if (_sync) {
// DEBUG
		// digitalWrite(SIGNAL_OUTPUT, val);
	// }



// ToDo
// calculate frame time?

	
	// suppress short spikes
	if (delta > (TIMECODE_THRESHOLD / 2)) {
// _peak();

		// long time
		// is logic 0 of 1+0
		if (delta > TIMECODE_THRESHOLD) {

			// 0 bit following 1 bit
			if (!_start) {
				_start = true;
			}

			// is 0 bit
			else {

			}

			// must be bit start
			_start = true;
			_add(0);
		}


		// short time
		// half bit
		else {

			// is mid bit > add logic 1
			if (_start) {
				_start = false;
			}

			else {
				_add(1);
				_start = true;
			}
		}
	}

	// return sync status
	return _sync;
}


// ===========================================
// return sync status
bool READER::sync(void) {
	return _sync;
}


// ===========================================
// True if a new value is available
bool READER::available(void) {
	return _tc.changed();
}


// ===========================================
// framerate has changed
bool READER::fps_changed(void) {
	return _tc.fps_changed();
}


// ===========================================
// get framerate


// ===========================================
// get timecode structure
TIMECODE READER::get(void) {
	return _tc.get();
}


// ===========================================
// add bit to buffer
void READER::_add(bool bit) {

	uint8_t byte_count = _counter >> 3;
	uint8_t bit_count = _counter & 0b111;


	// is synced and bit 0-63 > write data
	if (_sync && _counter < 64) {

		// set bit in reverse order >> LSB to the left
		if (bit) {
			_raw_timecode[byte_count] |= (1 << bit_count);
		}

		// clear bit
		else {
			_raw_timecode[byte_count] &= ~(1 << bit_count);
		}


		// increment bit counter
		_inc();
	}


	// check sync word
	else if (_check_sync_word(bit)) {
		_sync = true;

		// is in sync > reset and set sync to true
		_reset();
	}
}


// ===========================================
// increment counter
// return bit index (0-79)
// reset sync -> sync word must follow
uint8_t READER::_inc(void) {

	_counter ++;

	// end of data count (8 byte)
	// write data
	if (_counter == 64) {

		_tc.set(_raw_timecode);
	}


	// overflow > is not sync
	if (_counter >= 80) {
		_sync = false;
		_reset();
	}

	return _index();
}


uint8_t READER::_reverse(uint8_t b) {
   b = (b & 0xF0) >> 4 | (b & 0x0F) << 4;
   b = (b & 0xCC) >> 2 | (b & 0x33) << 2;
   b = (b & 0xAA) >> 1 | (b & 0x55) << 1;
   return b;
}


// ===========================================
// get bit index
uint8_t READER::_index(void) {
	return _counter;
}


// ===========================================
// reset counter
void READER::_reset(void) {
	_counter = 0;
}


// ===========================================
// add bit to sync word and check
// return true, if sync word found
// sync word: 0b0011111111111101
bool READER::_check_sync_word(bool bit) {

	bool sync = false;

	// 16 bit register
	// shift left and add bit
	// compare with sync word
	_sync_register = (_sync_register << 1) | bit;

	if (_sync_register == _sync_word) {
		sync = true;
	}

	return sync;
}


// DEBUG
// create peak
void READER::_peak(void) {
	_rect();
	_rect();
}


void READER::_rect(void) {
	digitalWrite(SIGNAL_OUTPUT, !digitalRead(SIGNAL_OUTPUT));
}

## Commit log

2024-08-09 timecode generation stable version slate clapping button integrated for free run mode
2024-08-09 bugfixes in timecode output
    [DigislatePlus.ino]
2024-08-11 slate function implemented bugfix in rtc-timecode synchronisation status display expanded
    [DigislatePlus.ino, led.cpp]
2024-08-12 hardware documentation added
    [Digislate Full.3mf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]
2024-08-14 KiCAD PCD design project added
    [DigiSlatePlus.kicad_pcb, DigiSlatePlus.kicad_sch]
2024-08-14 PCD design added
    [DigiSlatePlus.kicad_pcb, DigiSlatePlus.kicad_sch]
2024-08-14 TP4056 library added
    [DigiSlatePlus.kicad_pcb, DigiSlatePlus.kicad_sch]
2024-08-18 KiCAD libraries added
2024-08-19 file cleanup
    [DigiSlatePlus.kicad_pcb, DigiSlatePlus.kicad_sch, Digislate Full.3mf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]
2024-08-19 Schematic updated
    [DigiSlatePlus.kicad_pcb, DigiSlatePlus.kicad_sch]
2024-08-21 change page structure
    [DigiSlatePlus-Power.kicad_sch, DigiSlatePlus.kicad_pcb, DigiSlatePlus.kicad_sch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]
2024-08-22 schematic and board layout finished
    [DigiSlatePlus-Power.kicad_sch, DigiSlatePlus.kicad_pcb, DigiSlatePlus.kicad_sch]
2024-08-22 first finished schematic version
    [DigiSlatePlus-Power.kicad_sch, DigiSlatePlus.kicad_pcb, DigiSlatePlus.kicad_sch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]
2024-08-28 Rename hardware/Bill of materials.md to hardware/DigiSlate - original/Bill of materials.md
2024-08-28 Rename hardware/DigiSlate - original/Bill of materials.md to hardware/DigiSlate - original/DigiSlate - original/Bill of materials.md
2024-08-28 Rename hardware/DigiSlate - original/DigiSlate - original/Bill of materials.md to hardware/DigiSlate - original/Bill of materials.md
2024-08-28 Rename hardware/Bill Of Material.pdf to hardware/DigiSlate - original/Bill Of Material.pdf
2024-09-05 final 1.0 board version
    [DigiSlatePlus-Power.kicad_sch, DigiSlatePlus.kicad_pcb, DigiSlatePlus.kicad_sch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]
2024-09-09 bugfixes in board
    [DigiSlatePlus.kicad_pcb, DigiSlatePlus.kicad_sch]
2024-09-15 reader method first reading status getting framerate not verified
2024-09-15 jam mode to write the timecode from the input to thr rtc added frame offset is still missing
    [DigislatePlus.ino, reader.cpp, setup.h]
2024-09-24 add button class
2024-09-24 add button class to settings class
